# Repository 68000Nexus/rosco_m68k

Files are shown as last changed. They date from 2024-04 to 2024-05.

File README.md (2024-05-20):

# Really Old-School Computer - M68K
## A Motorola 68k Single-Board Computer

> **Note**: This is the **develop** branch, where the latest development files live. It is not guaranteed to contain stable code or working designs at any given point. If you are looking for code to use with your board or stable designs, these can be found on the relevant release branches: The [latest 2.4 release branch](https://github.com/rosco-m68k/rosco_m68k/tree/release/version-2.4) for revision 2.x boards, the [1.3 release branch](https://github.com/rosco-m68k/rosco_m68k/tree/release/version-1.3), the [1.2 release branch](https://github.com/rosco-m68k/rosco_m68k/tree/release/revision-1.2) for **revision 1.2** boards, or the [1.1 release branch](https://github.com/rosco-m68k/rosco_m68k/tree/release/revision-1.1) (or the [1.01 release branch if you have firmware 1.01](https://github.com/rosco-m68k/rosco_m68k/tree/release/revision-1.01)) for **revision 1 boards**. Code built or PCBs manufactured from the develop branch are likely to contain development and pre-production bugs, be incomplete, or just plain not work. Code and designs here are liable to change in utterly-incompatible ways without notice!

## Boards & Kits Available

> **The best way to support this project is to buy PCBs and kits - visit the <a href='https://store.rosco-m68k.com'>Official Store</a>!**

> Alternatively, you can <a href="https://ko-fi.com/rosco_m68k">buy us a coffee</a> if you like, it would be much appreciated! 😊

## What is this?

This repository holds design files, firmware and software for the Really Old-School Computer 
(M68k) single-board computer, AKA the rosco_m68k. This is a fully-featured, programmable,
extensible and capable 16/32-bit retro computer that is completely open source.

This project contains all the design files and source code for the project. For 
documentation (including assembly instructions) please see https://rosco-m68k.com

You can find the project along with some logs about its development history
on Hackaday: https://hackaday.io/project/164305-yet-another-m68k-homebrew

* All Software released under the MIT licence. See LICENSE for details.
* All Hardware released under the CERN Open Hardware licence.See LICENCE.hardware.txt.
* All Documentation released under Creative Commons Attribution. See https://creativecommons.org/licenses/by/2.0/uk/
* OSHWA-certified Open Source Hardware

## Specifications

Current main board

### Hardware

The hardware specifications for the rosco_m68k are:

* MC68010P10 at 10MHz.
* XR68C681P provides UART, Timers and SD Card / SPI
* 1MB RAM (0x0 - 0xFFFFF)
* 1MB ROM (0xE00000 - 0xEFFFFF)
* 1MB IO space (0xF00000 - 0xFFFFFF)
* High-speed decode and glue logic handled by Atmel F22V10C PLDs.
* Comprehensive expansion and IO connectors allow the system to be easily expanded!

### Software

* A serial bootloader that can load software via the UART (with Kermit protocol)
* Lots of example code and community projects
* Rich firmware interface for with serial and video console for easy programming
* Programmable in assembly, C and (a limited subset of) C++.
* Easy68K-compatible* TRAP 15 (IO) handler
* A growing collection of system libraries and utility code
* Custom Homebrew tap with toolchain - assembly built with VASM; C/C++ built with GCC 10.2.

(*) The firmware is _mostly_ Easy68K compatible - certain functions are not implemented due to the serial nature of IO.

## Getting boards fabricated

If you want to get boards fabricated, we recommend JLCPCB - they do all of our commercial boards. 
These are the options you'll want when ordering from them (these should be readily adaptable to other fabs too!)

JLCPCB Fab Options

## Certification

The rosco_m68k is an OSHWA-certified Open Source Hardware project!

<p align='center'>
OSHWA Certified OSHWA Certification UK000006
</p>
<p align='center'>
https://certification.oshwa.org/uk000006.html
</p>

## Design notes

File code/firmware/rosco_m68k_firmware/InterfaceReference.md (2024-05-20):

# rosco_m68k Firmware - Memory & Interfaces
## Firmware version 2.0

This document describes the interfaces provided for programmers,
hardware integrators and those expanding the rosco_m68k, as it
applies to firmware revision 2.0. 

The information contained herein is accurate and complete as far
as possible, and will be kept updated as firmware 2.0 is developed.

# Contents

* 1. TRAP Interfaces for User Code
  * 1.1. SPI & Block device IO (TRAP 13)
    * 1.1.1 Example Usage
    * 1.1.2 Functions
      * 1.1.2.1 CHECK_SD_SUPPORT (Function #0)
      * 1.1.2.2 SD_INIT (Function #1)
      * 1.1.2.3 SD_READ_BLOCK (Function #2)
      * 1.1.2.4 SD_WRITE_BLOCK (Function #3)
      * 1.1.2.5 SD_READ_REGISTER (Function #4)
      * 1.1.2.6 CHECK_SPI (Function #5)
      * 1.1.2.7 SPI_INIT (Function #6)
      * 1.1.2.8 SPI_ASSERT_CS (Function #7)
      * 1.1.2.9 SPI_DEASSERT_CS (Function #8)
      * 1.1.2.10 SPI_TRANSFER_BYTE (Function #9)
      * 1.1.2.11 SPI_TRANSFER_BUFFER (Function #10)
      * 1.1.2.12 SPI_RECV_BYTE (Function #11)
      * 1.1.2.13 SPI_RECV_BUFFER (Function #12)
      * 1.1.2.14 SPI_SEND_BYTE (Function #13)
      * 1.1.2.15 SPI_SEND_BUFFER (Function #14)
      * 1.1.2.16 CHECK_ATA_SUPPORT (Function #15)
      * 1.1.2.17 ATA_INIT (Function #16)
      * 1.1.2.18 ATA_READ_SECTORS (Function #17)
      * 1.1.2.19 ATA_WRITE_SECTORS (Function #18)
      * 1.1.2.20 ATA_IDENTIFY (Function #19)
  * 1.2. Character device IO routines (TRAP 14)
    * 1.2.1 Example Usage
    * 1.2.2 Functions
      * 1.2.2.1 PRINT (Function #0)
      * 1.2.2.2 PRINTLN (Function #1)
      * 1.2.2.3 SENDCHAR (Function #2)
      * 1.2.2.4 RECVCHAR (Function #3)
      * 1.2.2.5 PRINTCHAR (Function #4)
      * 1.2.2.6 SETCURSOR (Function #5)
      * 1.2.2.7 CHECKCHAR (Function #6)
      * 1.2.2.8 CHECK_DEVICE_SUPPORT (Function #7)
      * 1.2.2.9 GET_DEVICE_COUNT (Function #8)
      * 1.2.2.10 GET_DEVICE (Function #9)
      * 1.2.2.11 ADD_DEVICE (Function #10)
      * 1.2.2.12 DEVICE_RECVCHAR (Function #11)
      * 1.2.2.13 DEVICE_SENDCHAR (Function #12)
      * 1.2.2.14 DEVICE_CHECKCHAR (Function #13)
      * 1.2.2.15 RESERVED (Function #14)
      * 1.2.2.16 RESERVED (Function #15)
      * 1.2.2.17 DEVICE_CTRL (Function #16)
      * 1.2.2.18 INPUTCHAR (Function #17)
      * 1.2.2.19 CHECKINPUT (Function #18)
  * 1.3. Easy68k compatibility layer (TRAP 15)
    * 1.3.1 Example Usage
    * 1.3.2 Functions
      * 1.3.2.1 PRINTLN_LEN (Function #0)
      * 1.3.2.2 PRINT_LEN (Function #1)
      * 1.3.2.3 READSTR (Function #2)
      * 1.3.2.4 DISPLAYNUM_SIGNED (Function #3)
      * 1.3.2.5 READNUM (Function #4)
      * 1.3.2.6 READCHAR (Function #5)
      * 1.3.2.7 SENDCHAR (Function #6)
      * 1.3.2.8 CHECKINPUT (Function #7)
      * 1.3.2.9 GETUPTICKS (Function #8)
      * 1.3.2.10 TERMINATE (Function #9)
      * 1.3.2.11 MOVEXY (Function #11)
      * 1.3.2.12 SETECHO (Function #12)
      * 1.3.2.13 PRINTLN_SZ (Function #13)
      * 1.3.2.14 PRINT_SZ (Function #14)
      * 1.3.2.15 PRINT_UNSIGNED (Function #15)
      * 1.3.2.16 SETDISPLAY (Function #16)
      * 1.3.2.17 PRINTSZ_NUM (Function #17)
      * 1.3.2.18 PRINTSZ_READ_NUM (Function #18)
      * 1.3.2.19 PRINTNUM_SIGNED_WIDTH (Function #20)
* 2. System Data Area memory map
  * 2.1. Exception vectors
  * 2.2. Basic System Data Block (SDB)
  * 2.3. Extension Function Pointer Table (EFPT)
  * 2.4. Video IO Data Area (VDA)
  * 2.5. Firmware Reserved Area 1 (Internal)
  * 2.6. Firmware Reserved Area 2 (BSS)
* 3. Character Devices
  * 3.1 General Information
  * 3.2. The `CHAR_DEVICE` structure
  * 3.3. Device function calling conventions

# 1. TRAP Interfaces for User Code

The firmware provides a set of basic IO routines intended for use
from user code. Because some of these routines may require the CPU
to be in Supervisor mode, they are accessed via the M68k TRAP
instruction. Execution of this instruction causes the CPU to jump
to an exception vector (initialized by the firmware) as if an
exception were being processed. Context is stored on the stack
and Supervisor mode is entered automatically.

Currently, three TRAPs are used by the firmware:

* TRAP 13 provides rosco_m68k's native block device IO routines (SD)
* TRAP 14 provides rosco_m68k's native serial device IO routines (UART/Console)
* TRAP 15 provides basic IO routines that are broadly Easy68k-compatible(*)

All other TRAP vectors are unused at boot-time (and initialized to no-op
handlers). Extension code, drivers and user code are free to re-use
these vectors as they see fit.

The standard TRAP handlers use various registers as arguments, and
may also use one or more registers to return values to the 
calling code. These registers are documented in the following 
sections. In all cases, all registers other than those stated
in this documentation are preserved.

**Note** that the standard firmware TRAP handlers rely on the 
integrity of the System Data Area in memory. If this area is
reused or corrupted, these routines may not function properly.

(*) Note that the Easy68k layer may optionally be omitted from the 
firmware build. In such cases, the functions offered on TRAP 15 will
not be available, and that TRAP vector may be reused.

## 1.1. Block device IO (TRAP 13)

TRAP 13 provides access to the block-device IO functionality
provided by the firmware. At present, this means SD cards.

Register D0.L is expected to contain the function code (note that
this is different to the TRAP 14 handler!). Other arguments
depend on the specific function, and are documented below.

In all cases, registers used as aguments (including D0.L) are **not** 
guaranteed to be preserved. All other registers are preserved.

Function codes outside the range documented here are considered
reserved for future expansion, and should not be used by integrators
or other code. The exception to this is where the user program 
is intended to take complete control of the system, in which case
the TRAP handlers, and the SDA that underpins them, may be entirely
replaced in the scope of that program.

### 1.1.1 Example Usage

An example of using function 2 (SD_READ_BLOCK) of TRAP 13 is:

```
SD_read_block::
    movem.l A0-A2/D1,-(A7)
    move.l  (20,A7),A1
    move.l  (24,A7),D1
    move.l  (28,A7),A2
    move.l  #2,D0
    trap    #13
    movem.l (A7)+,A0-A2/D1
    rts
```

With GCC as the compiler, this could be called directly from C, 
with the prototype: 

```
bool SD_read_block(SDCard *sd, uint32_t block, void *buf);
```
 
### 1.1.2 Functions

#### 1.1.2.1 CHECK_SD_SUPPORT (Function #0)

**Arguments**

* D0.L - 0 (Function code)

**Modifies**

* `D0.L` - Return value

**Description**

Determine whether SD Card support is present in the Firmware.

Where SD Card support is available, this will return the magic
number $1234FEDC in D0.L. 

Any other value indicates that support is not available. In this
case, none of the SD Card routines should be used.

With Firmware 2.0, SD support is always available. However, this
routine is retained to allow easy backward-compatibility.

#### 1.1.2.2 SD_INIT (Function #1)

**Arguments**

* `D0.L` - 1 (Function code)
* `A1`   - Pointer to an SDCard struct

**Modifies**

* `D0.L` - Return value
* `A0`   - Modified arbitrarily
* `A1`   - May be modified arbitrarily

**Description**

Attempt to initialize the SD Card. 

The memory pointed to by A1 will be a SDCard structure - see
sdfat.h in the standard libraries for details.

The return value in D0.L will be one of the SDInitStatus
codes - `SD_INIT_OK` (ordinal 0) indicates success, while failure 
is indicated by any other value. Again, see sdfat.h for details.

#### 1.1.2.3 SD_READ_BLOCK (Function #2)

**Arguments**

* `D0.L` - 2 (Function code)
* `D1.L` - Block number to read
* `A1`   - Pointer to an initialized SDCard struct
* `A2`   - Pointer to a 512-byte buffer

**Modifies**

* `D0.L` - Return value
* `D1.L` - May be modified arbitrarily
* `A0`   - Modified arbitrarily
* `A1`   - May be modified arbitrarily
* `A2`   - May be modified arbitrarily

**Description**

Read a 512-byte block from the SD Card into the buffer
pointed to by A2.

Returns 0 in D0.L to indicate failure, any other value
indicates success.

#### 1.1.2.4 SD_WRITE_BLOCK (Function #3)

**Arguments**

* `D0.L` - 3 (Function code)
* `D1.L` - Block number to write
* `A1`   - Pointer to an initialized SDCard struct
* `A2`   - Pointer to a 512-byte buffer

**Modifies**

* `D0.L` - Return value
* `D1.L` - May be modified arbitrarily
* `A0`   - Modified arbitrarily
* `A1`   - May be modified arbitrarily
* `A2`   - May be modified arbitrarily

**Description**

Write a 512-byte block from the buffer pointed to by A2 to
the SD Card..

Returns 0 in D0.L to indicate failure, any other value
indicates success.

#### 1.1.2.5 SD_READ_REGISTER (Function #4)

**Arguments**

* `D0.L` - 4 (Function code)
* `D1.L` - Register number to read (translates directly to a CMD)
* `A1`   - Pointer to an initialized SDCard struct
* `A2`   - Pointer to a 16-byte buffer

**Modifies**

* `D0.L` - Return value
* `D1.L` - May be modified arbitrarily
* `A0`   - Modified arbitrarily
* `A1`   - May be modified arbitrarily
* `A2`   - May be modified arbitrarily

**Description**

Read an SD Card register block from the SD Card into the buffer
pointed to by A2.

Returns 0 in D0.L to indicate failure, any other value
indicates success.

#### 1.1.2.6 CHECK_SPI (Function #5)

**Arguments**

* `D0.L` - 5 (Function code)

**Modifies**

* `D0.L` - Return value

**Description**

Determine whether SPI support is present in the Firmware.

Where SPI Card support is available, this will return the magic
number $1234FEDC in D0.L. 

Any other value indicates that support is not available. In this
case, none of the SPI routines should be used.

With Firmware 2.0, SD support is always available. However, this
routine is retained to allow easy backward-compatibility.

#### 1.1.2.7 SPI_INIT (Function #6)

**Arguments**

* `D0.L` - 6 (Function code)

**Modifies**

* `D0.L` - Result (0 = OK, otherwise failed)
* `A0`   - Modified arbitrarily

**Description**

Initialize the SPI interface. This sets the SPI pins to the 
appropriate modes (input vs output).

#### 1.1.2.8 SPI_ASSERT_CS (Function #7)

**Arguments**

* `D0.L` - 7 (Function code)
* `D1.L` - Device number (0 or 1)

**Modifies**

* `D0.L` - Result (0 = failed, otherwise OK)
* `A0`   - Modified arbitrarily

**Description**

Assert the appropriate CS line. Note that asserting one line 
*does not* automatically deassert the other!

#### 1.1.2.9 SPI_DEASSERT_CS (Function #8)

**Arguments**

* `D0.L` - 8 (Function code)
* `D1.L` - Device number (0 or 1)

**Modifies**

* `D0.L` - Result (0 = failed, otherwise OK)
* `A0`   - Modified arbitrarily

**Description**

Deassert the appropriate CS line. 

#### 1.1.2.10 SPI_TRANSFER_BYTE (Function #9)

**Arguments**

* `D0.L` - 9 (Function code)
* `D1.L` - Byte to send

**Modifies**

* `D0.L` - Byte received
* `A0`   - Modified arbitrarily

**Description**

Send and receive a byte (exchange) via SPI.

#### 1.1.2.11 SPI_TRANSFER_BUFFER (Function #10)

**Arguments**

* `D0.L` - 10 (Function code)
* `A1.L` - Pointer to buffer
* `D1.L` - Number of bytes

**Modifies**

* `D0.L` - Count exchanged
* `A0`   - Modified arbitrarily
* `A1`   - Possibly modified

**Description**

Transfer count (`D1.L`) bytes from the given buffer, exchanging them 
with bytes received at the same time (and returned in the buffer).

Note that the buffer pointer may be modified, so keep a copy locally.

#### 1.1.2.12 SPI_RECV_BYTE (Function #11)

**Arguments**

* `D0.L` - 11 (Function code)

**Modifies**

* `D0.L` - Byte received
* `A0`   - Modified arbitrarily

**Description**

Send and receive a byte (exchange) via SPI.

#### 1.1.2.13 SPI_RECV_BUFFER (Function #12)

**Arguments**

* `D0.L` - 12 (Function code)
* `A1.L` - Pointer to buffer
* `D1.L` - Number of bytes

**Modifies**

* `D0.L` - Count received
* `A0`   - Modified arbitrarily
* `A1`   - Possibly modified

**Description**

Receive count (`D1.L`) bytes into the given buffer.
Note that the buffer pointer may be modified, so keep a copy locally.

#### 1.1.2.14 SPI_SEND_BYTE (Function #13)

**Arguments**

* `D0.L` - 13 (Function code)
* `D1.L` - Byte to send

**Modifies**

* `A0`   - Modified arbitrarily
* `D1.L` - Possibly trashed

**Description**

Send and receive a byte (exchange) via SPI.

#### 1.1.2.15 SPI_SEND_BUFFER (Function #14)

**Arguments**

* `D0.L` - 14 (Function code)
* `A1.L` - Pointer to buffer
* `D1.L` - Number of bytes

**Modifies**

* `D0.L` - Count received
* `A0`   - Modified arbitrarily
* `A1`   - Possibly modified

**Description**

Send count (`D1.L`) bytes from the given buffer.
Note that the buffer pointer may be modified, so keep a copy locally.

#### 1.1.2.16 CHECK_ATA_SUPPORT (Function #15)

**Arguments**

* `D0.L` - 15 (Function code)

**Modifies**

* `D0.L` - Return value

**Description**

Determine whether ATA support is present in the Firmware.

Where ATA support is available, this will return the magic
number $1234FEDC in D0.L. 

Any other value indicates that support is not available. In this
case, none of the ATA routines should be used.

With Firmware 2.0, ATA support is always available. However, this
routine is retained to allow easy backward-compatibility.

#### 1.1.2.17 ATA_INIT (Function #16)

**Arguments**

* `D0.L` - 16 (Function code)
* `D1.L` - 0 (ATA Master) or 1 (ATA slave)
* `A1`   - Pointer to an ATADevice struct

**Modifies**

* `D0.L` - Return value
* `D1.L` - May be modified arbitrarily
* `A0`   - Modified arbitrarily
* `A1`   - May be modified arbitrarily

**Description**

Attempt to initialize an ATA device. 

The memory pointed to by A1 will be a ATADevice structure - see
ata.h in the standard libraries for details.

The return value in D0.L will be one of the ATAInitStatus
codes - `ATA_INIT_OK` (ordinal 0) indicates success, while failure 
is indicated by any other value. Again, see ata.h for details.

#### 1.1.2.18 ATA_READ_SECTORS (Function #17)

**Arguments**

* `D0.L` - 17 (Function code)
* `D1.L` - LBA sector number to read
* `D2.L` - Number of sectors to read
* `A1`   - Pointer to an initialized ATADevice struct
* `A2`   - Pointer to a (512 * D2.L)-byte buffer

**Modifies**

* `D0.L` - Return value
* `D1.L` - May be modified arbitrarily
* `A0`   - Modified arbitrarily
* `A1`   - May be modified arbitrarily
* `A2`   - May be modified arbitrarily

**Description**

Read the number of 512-byte sectors (indicated by `D2.L`) from the 
ATA device into the buffer pointed to by `A2`.

Returns the actual number of sectors read in `D0.L`.

#### 1.1.2.19 ATA_WRITE_SECTORS (Function #18)

**Arguments**

* `D0.L` - 18 (Function code)
* `D1.L` - LBA sector number to write
* `D2.L` - Number of sectors to write
* `A1`   - Pointer to an initialized ATADevice struct
* `A2`   - Pointer to a (512 * D2.L)-byte buffer

**Modifies**

* `D0.L` - Return value
* `D1.L` - May be modified arbitrarily
* `A0`   - Modified arbitrarily
* `A1`   - May be modified arbitrarily
* `A2`   - May be modified arbitrarily

**Description**

Write the number of 512-byte sectors (indicated by `D2.L`) from the 
buffer pointed to by `A2` to the ATA device, starting at the LBA sector
indicated by `D1.L`.

Returns the actual number of sectors written in `D0.L`.

#### 1.1.2.20 ATA_IDENTIFY (Function #19)

**Arguments**

* `D0.L` - 19 (Function code)
* `A1`   - Pointer to an initialized ATADevice struct
* `A2`   - Pointer to a 512-byte buffer

**Modifies**

* `D0.L` - Return value (0 = failed, 1 = success)
* `D1.L` - May be modified arbitrarily
* `A0`   - Modified arbitrarily
* `A1`   - May be modified arbitrarily
* `A2`   - May be modified arbitrarily

**Description**

Issue an ATA `IDENTIFY` command to the specified `ATADevice`, and return
the results in the supplied buffer.

Returns 1 in `D0.L` if successful, 0 otherwise.

## 1.2. Basic IO routines (TRAP 14)

TRAP 14 provides access to the character-based IO functionality 
provided by the firmware. This includes the default UART and
console.

Register D1.L is expected to contain the function code. Other arguments
depend on the specific function, and are documented below.

In all cases, registers used as aguments (**excluding** D1.L, which 
will be preserved unless explicitly documented as used for a return
value) are **not** guaranteed to be preserved. All 
other registers are preserved.

Function codes outside the range documented here are considered
reserved for future expansion, and should not be used by integrators
or other code. The exception to this is where the user program 
is intended to take complete control of the system, in which case
the TRAP handlers, and the SDA that underpins them, may be entirely
replaced in the scope of that program.

### 1.2.1 Example Usage

An example of calling function 1 (PRINTLN) of TRAP 14 is:

```
DO_PRINTLN:
    move.l  #1,D1
    lea.l   MYSTRING,A0
    trap    #14

; ... later

MYSTRING    dc.b    "Hello, World!", 0
```

### 1.2.2 Functions

#### 1.2.2.1 PRINT (Function #0)

**Arguments**

* `D1.L` - 0 (Function code)
* `A0`   - Pointer to null-terminated string to print

**Modifies**

* `A0`   - Will point to the memory location following the null terminator

**Description**

Print the null-terminated string pointed to by `A0` to the system's
*default console*. 

Where the default console is a serial terminal, this routine may block until
there is space in the UART's transmit buffer for the character - as such, 
it is not suitable for use in time- or latency-critical code (e.g. interrupt 
handlers).

The default console is initialized at boot-time by the firmware, and 
may be the V9958 console (where available), or the *default serial UART*.
For details on the default UART, see the `SENDCHAR` function.

System integrators and third-party hardware developers may also override
the default console (for example to output to third-party video 
hardware). See section 2.3 for details.

#### 1.2.2.2 PRINTLN (Function #1)

**Arguments**

* `D1.L` - 1 (Function code)
* `A0`   - Pointer to null-terminated string to print

**Modifies**

* `A0`   - Will point to the memory location following the null terminator

**Description**

Print the null-terminated string pointed to by `A0` to the system's
*default console* followed by a CR/LF sequence.

Where the default console is a serial terminal, this routine may block until
there is space in the UART's transmit buffer for the character - as such, 
it is not suitable for use in time- or latency-critical code (e.g. interrupt 
handlers).

The default console is initialized at boot-time by the firmware, and 
may be the V9958 console (where available), or the *default serial UART*.
For details on the default UART, see the `SENDCHAR` function.

System integrators and third-party hardware developers may also override
the default console (for example to output to third-party video 
hardware). See section 2.3 for details.

#### 1.2.2.3 SENDCHAR (Function #2)

**Arguments**

* `D1.L` - 2 (Function code)
* `D0.B` - Character to send

**Modifies**

Nothing

**Description**

Synchronously send the character contained in `D0.B` via the system's
*default UART*. This routine may block until there is space in the 
UART's transmit buffer for the character - as such, it is not suitable
for use in time- or latency-critical code (e.g. interrupt handlers).

The default UART is initialized at boot-time by the firmware, and
will generally be the "best" serial UART available (with the 
fallback being the MC68901 UART that is expected to be always installed).

System integrators and third-party hardware developers may also override
the default UART (for example to utilise third-party hardware). 
See section 2.3 for details.

#### 1.2.2.4 RECVCHAR (Function #3)

**Arguments**

* `D1.L` - 3 (Function code)

**Modifies**

* `D0.B` - Returns the received character

**Description**

Synchronously receive a character via the system's *default UART*,
and return it in `D0.B`. If no character is immediately available, this
routine will block until one becomes available. As such, it is not suitable
for use in time- or latency-critical code (e.g. interrupt handlers).

The default UART is initialized at boot-time by the firmware, and
will generally be the "best" serial UART available (with the 
fallback being the MC68901 UART that is expected to be always installed).

System integrators and third-party hardware developers may also override
the default UART (for example to utilise third-party hardware). 
See section 2.3 for details.

#### 1.2.2.5 PRINTCHAR (Function #4)

**Arguments**

* `D1.L` - 4 (Function code)
* `D0.B` - Character to print

**Modifies**

Nothing

**Description**

Print the character in `D0.B` to by `A0` to the system's *default console*.

Where the default console is a serial terminal, this routine may block until
there is space in the UART's transmit buffer for the character - as such, 
it is not suitable for use in time- or latency-critical code (e.g. interrupt 
handlers).

The default console is initialized at boot-time by the firmware, and 
may be the V9958 console (where available), or the *default serial UART*.
For details on the default UART, see the `SENDCHAR` function.

System integrators and third-party hardware developers may also override
the default console (for example to output to third-party video 
hardware). See section 2.3 for details.

#### 1.2.2.6 SETCURSOR (Function #5)

**Arguments**

* `D1.L` - 5 (Function code)
* `D0.B` - 0 to hide cursor, non-zero to show

**Modifies**

Nothing

**Description**

Show or hide the cursor on the *default console*. Where this is not possible]
(e.g. where the default console is a serial terminal) this routine does
nothing.

The default console is initialized at boot-time by the firmware, and 
may be the V9958 console (where available), or the *default serial UART*.
For details on the default UART, see the `SENDCHAR` function.

System integrators and third-party hardware developers may also override
the default console (for example to output to third-party video 
hardware). See section 2.3 for details.

#### 1.2.2.7 CHECKCHAR (Function #6)

**Arguments**

* `D1.L` - 6 (Function code)

**Modifies**

* `D0.B` - 0 if no character waiting, nonzero otherwise

**Description**

Determine whether the system's *default UART* has a character waiting to
be received, returning non-zero in `D0.B` if so, zero otherwise. 

This can be used to determine whether a call to `RECVCHAR` will block.
Note that this function may clear error flags and other status information.

The default UART is initialized at boot-time by the firmware, and
will generally be the "best" serial UART available (with the 
fallback being the MC68901 UART that is expected to be always installed).

System integrators and third-party hardware developers may also override
the default UART (for example to utilise third-party hardware). 
See section 2.3 for details.

#### 1.2.2.8 CHECK_DEVICE_SUPPORT (Function #7)

**Arguments**

* `D1.L` - 7 (Function code)

**Modifies**

* `D0.L` - Return value

**Description**

Check if the new _Character Device Support_ (available since firmware
2.30) is available.

Where support is available, this will return the magic number $1234FEDC 
in `D0.L`.

Any other value indicates that support is not available. In this
case, none of the character device routines should be used.

#### 1.2.2.9 GET_DEVICE_COUNT (Function #8)

**Arguments**

* `D1.L` - 8 (Function code)

**Modifies**

* `D0.W` - Return value

**Description**

Returns the number of character devices the firmware knows about in 
`D0.W`.

#### 1.2.2.10 GET_DEVICE (Function #9)

**Arguments**

* `D1.L` - 9 (Function code)
* `D0.W` - 0-based index of the desired device
* `A0`   - Points to a `CHAR_DEVICE` structure (32 bytes)

**Modifies**

* `D0.B` - `0` if the device number is not valid, nonzero otherwise
* `A0`   - Trashed

**Description**

Populates the supplied device structure with data for the
specified device number. 

Note that the data is copied into the structure you supply,
you cannot use this to modify system data structures.

#### 1.2.2.11 ADD_DEVICE (Function #10)

**Arguments**

* `A0`   - Pointer to a new `CHAR_DEVICE` structure
* `D1.L` - 10 (Function code)

**Modifies**

* `D0.B` - 0-15 index of the device. Any other value indicates failure.

**Description**

Adds a new character device at the next available slot. There
are sixteen slots - if they are all full, this function will return
a value >15 to indicate failure.

#### 1.2.2.12 DEVICE_RECVCHAR (Function #11)

**Arguments**

* `D1.L` - 11 (Function code)
* `A0`   - Pointer to the `CHAR_DEVICE` structure (obtained via `GET_DEVICE`)

**Modifies**

* `D0.B` - Returns the received character
* `A0`   - Trashed 

**Description**

Synchronously receive a character via the character device in the supplied
`CHAR_DEVICE` structure, and return it in `D0.B`. 

If no character is immediately available, this routine _may_ block until one
becomes available. As such, it is not suitable for use in time- or 
latency-critical code (e.g. interrupt handlers).

#### 1.2.2.13 DEVICE_SENDCHAR (Function #12)

**Arguments**

* `D1.L` - 12 (Function code)
* `D0.B` - Character to send
* `A0`   - Pointer to the `CHAR_DEVICE` structure (obtained via `GET_DEVICE`)

**Modifies**

* `A0`   - Trashed 

**Description**

Synchronously send the character contained in `D0.B` via the character 
device referenced by the supplied `CHAR_DEVICE` structure. 

This routine _may_ block until there is space in the device's buffer
for the character - as such, it is not suitable for use in time- or 
latency-critical code (e.g. interrupt handlers).

#### 1.2.2.14 DEVICE_CHECKCHAR (Function #13)

**Arguments**

* `D1.L` - 13 (Function code)
* `A0`   - Pointer to the `CHAR_DEVICE` structure (obtained via `GET_DEVICE`)

**Modifies**

* `D0.B` - 0 if no character waiting, nonzero otherwise
* `A0`   - Trashed 

**Description**

Determine whether the the character device referenced by the supplied
 `CHAR_DEVICE` structure has a character waiting to be received, returning 
 non-zero in `D0.B` if so, zero otherwise. 

This can be used to determine whether a call to `DEVICE_RECVCHAR` will 
block if called for the same device.

Note that this function _may_ clear error flags and other status information.

#### 1.2.2.15 RESERVED (Function #14)

This function code is reserved for future use and should not be called.

#### 1.2.2.16 RESERVED (Function #15)

This function code is reserved for future use and should not be called.

#### 1.2.2.17 DEVICE_CTRL (Function #16)

**Arguments**

* `D1.L` - 16 (Function code)
* `D0.L` - Command (low-byte) and optional data
* `D2.L` - 32-bit command-specific parameter
* `A0`   - Pointer to the `CHAR_DEVICE` structure (obtained via `GET_DEVICE`)

**Modifies**

* `D0.L` - 0 if unknown command, device/command-specific result otherwise
* `A0`   - Trashed 

**Description**

Send a device-specific command, with optional parameters in the high
24 bits of `D0` and the full 32-bits of `D2`.

The commands supported, the parameters they take, and the return value
of this function are all device specific. See the specific documentation
for the device (which can be identified by the device type in the 
`CHAR_DEVICE` block) for details.

#### 1.2.2.18 INPUTCHAR (Function #17)

**Arguments**

* `D1.L` - 17 (Function code)

**Modifies**

* `D0.B` - The read character

**Description**

Read a character from the default input device. Will block until a
character is available.

In systems where the rosco_m68k (or compatible) keyboard is connected to the
second UART, this will check the keyboard. 

Otherwise, the default input will usually be the main UART.

#### 1.2.2.19 CHECKINPUT (Function #18)

**Arguments**

* `D1.L` - 18 (Function code)

**Modifies**

* `D0.B` - 0 if no character waiting, nonzero otherwise

**Description**

Check the default input device for a waiting character.

In systems where the rosco_m68k (or compatible) keyboard is connected to the
second UART, this will check the keyboard. 

Otherwise, the default input will usually be the main UART.

## 1.3. Easy68k compatibility layer (TRAP 15)

TRAP 15 provides an (optional, included by default) Easy68k-compatible
IO interface. The aim is to allow many common Easy68k programs to be 
run on the rosco_m68k without modification.

Currently only a subset of the Easy68K tasks are implemented. Output 
will always go to the **default console** (See section 1.1.2.1) and input
will be via the **default UART** (See section 1.1.2.3). Depending on
capabilities of the input and output devices, some functions may not
be available in all contexts (for example, cursor movement and color
setting will not be available where output is via UART).

These functions are called by loading the task number into `D0` and setting
up other registers as documented below, and then calling `TRAP #15`.

### 1.3.1 Example Usage

An example of calling function 0 (PRINTLN with length) of TRAP 15 is:

```
DO_EASY68K_PRINTLN_LEN:
    move.l  #0,D0
    move.w  #13,D1
    lea.l   MYSTRING,A1
    trap    #15

; ... later

MYSTRING    dc.b    "Hello, World!"
```

### 1.3.2 Functions

#### 1.3.2.1 PRINTLN_LEN (Function #0)

**Arguments**

* `D0.L` - 0 (Function code)
* `D1.W` - String length (max 255)
* `A1` - Points to the string

**Modifies**

* `D1` - Trashed
* `A1` - Points to memory location after the last printed character

**Description**

Print the string at (A1), D1.W bytes long (max 255) with carriage return
and line feed (CR, LF) to the system's *default console*. 

See also: Function 13

#### 1.3.2.2 PRINT_LEN (Function #1)

**Arguments**

* `D0.L` - 1 (Function code)
* `D1.W` - String length (max 255)
* `A1` - Points to the string

**Modifies**

* `D1` - Trashed
* `A1` - Points to memory location after the last printed character

**Description**

Print the string at (A1), D1.W bytes long (max 255) **without** carriage return
and line feed (CR, LF) to the system's *default console*. 

See also: Function 14

#### 1.3.2.3 READSTR (Function #2)

**Arguments**

* `D0.L` - 2 (Function code)
* `A0` - Pointer to buffer in which to store string

**Modifies**

* `D1.W` - Returns length of read string (Max 80)
* `(A1)` - Returns the string

**Description**

Read string from keyboard and store at (A1), NULL terminated, length retuned in D1.W (max 80). 

#### 1.3.2.4 DISPLAYNUM_SIGNED (Function #3)

**Arguments**

* `D0.L` - 3 (Function code)
* `D1.L` - Number to display

**Modifies**

* `D1` - Possibly trashed

**Description**

Print signed number in D1.L in decimal (in smallest field) to the system's
*default console*.

See also: Functions 15 & 20

#### 1.3.2.5 READNUM (Function #4)

**Arguments**

* `D0.L` - 4 (Function code)

**Modifies**

* `D1.L` - Returns the read number

**Description**

Read a number from the keyboard into D1.L.

See also: Functions 15 & 20

#### 1.3.2.6 READCHAR (Function #5)

**Arguments**

* `D0.L` - 5 (Function code)

**Modifies**

* `D1.B` - The read character.

**Description**

Read single character from the keyboard into D1.B.

**Note** Unlike Easy68k, this will block until input is available.

#### 1.3.2.7 SENDCHAR (Function #6)

**Arguments**

* `D0.L` - 6 (Function code)
* `D1.B` - Character to display

**Modifies**

* `D1` - Trashed

**Description**

Display single character in D1.B.

#### 1.3.2.8 CHECKINPUT (Function #7)

**Arguments**

* `D0.L` - 7 (Function code)

**Modifies**

* `D1.B` - 1 if input pending, 0 otherwise

**Description**

Set D1.B to 1 if keyboard input is pending, otherwise set to 0. 
Use Function 5 to read pending key.

**Notes**

**This function is to be avoided if possible**.

Using this function doesn't make a lot of sense in the current rosco_m68k 
environment, because all input is via the UART. This means that, while this 
function _is_ implemented, its meaning is subtly different from the Easy68K
equivalent - here true result means there is serial data waiting, not 
specifically a user keypress.

That's not the worst of it, however - if the MC68901 UART is currently the
system's *default UART*, **using this task may actually be harmful**.
It may silently clear any errors the UART is signalling. This is 
because it works by reading the Buffer Full indicator bit in the receiver
status register, which has the effect of _also_ clearing the error flags
(e.g. overrun) in that same register. Normally, these would be checked 
during a receive, but this task doesn't check them _at all_ and so could 
lead to errors being ignored / discarded.

So, if you must use this task, keep all this in mind! 

See also: Function 5                       

#### 1.3.2.9 GETUPTICKS (Function #8)

**Arguments**

* `D0.L` - 8 (Function code)

**Modifies**

* `D1.L` - Current number of upticks

**Description**

Return upticks (time in hundredths of a second since boot) in D1.L.

**Notes**

Easy68K defines this function as returning the count of "hundredths of a
second since midnight", but since the rosco_m68k doesn't have a real-time 
clock this just returns the system tick counter from the system data 
block (SDB), which is updated by the system tick handler (driven by a 
programmable interrupt which may be disabled).

Unfortunately this counter is only word-sized, and will roll over every
655.36 seconds (or 10.92 minutes if you prefer). It also isn't updated at
exactly 100HZ, so all-in-all this isn't really going to return "hundredths 
of a second since boot" unless you aren't particularly strict with your 
definition of "hundredths" and the computer was started less than ~11 minutes ago.

If you do need any kind of precision timing, you'll have to design some sort
of expansion that connects to the expansion bus :) 

#### 1.3.2.10 TERMINATE (Function #9)

**Arguments**

* `D0.L` - 9 (Function code)

**Modifies**

Nothing

**Description**

Terminate the program (Disables interrupts and halts the CPU).

This will never return - the only way back is through wetware
intervention.

#### 1.3.2.11 MOVEXY (Function #11)

**Arguments**

* `D0.L` - 11 (Function code)
* `D1.W` - Encoded position (see description)

**Modifies**

* `D1` - Trashed
* `D2` - Trashed
* `A0` - Trashed

**Description**

Position the cursor at ROW, COL. 

Support is not mandatory for any given console. E.g. requires ANSI support
on the receiving terminal where the default console is a UART.

* The high byte of D1.W holds the COL number (0-79),
* The low byte holds the ROW number (0-31).

0,0 is top left 79,31 is the bottom right (depending on terminal size).
Out of range coordinates are usually ignored (depends on terminal).

**Clear Screen : Set D1.W to $FF00**.

#### 1.3.2.12 SETECHO (Function #12)

**Arguments**

* `D0.L` - 12 (Function code)
* `D1.B` - 0 to disable, 1 to enable

**Modifies**

* `D1` - Trashed

**Description**

Keyboard Echo.

* D1.B = 0 to turn off keyboard echo.
* D1.B = non zero to enable it (default).

Echo is restored on 'Reset'.

#### 1.3.2.13 PRINTLN_SZ (Function #13)

**Arguments**

* `D0.L` - 13 (Function code)
* `A1` - Points to the string

**Modifies**

* `D1` - Trashed
* `A1` - Points to memory location after the last printed character

**Description**

Print the NULL-terminated string at (A1) with carriage return
and line feed (CR, LF) to the system's *default console*. 

See also: Function 0

#### 1.3.2.14 PRINT_SZ (Function #14)

**Arguments**

* `D0.L` - 14 (Function code)
* `A1` - Points to the string

**Modifies**

* `D1` - Trashed
* `A1` - Points to memory location after the last printed character

**Description**

Print the NULL-terminated string at (A1) **without** carriage return
and line feed (CR, LF) to the system's *default console*. 

See also: Function 1

#### 1.3.2.15 PRINT_UNSIGNED (Function #15)

**Arguments**

* `D0.L` - 15 (Function code)
* `D1.L` - Number to print
* `D2.B` - Base (2 through 36)

**Modifies**

* `D1` - Trashed
* `D2` - Trashed

**Description**

Display the unsigned number in D1.L converted to number base (2 
through 36) contained in D2.B.

For example, to display D1.L in base16 put 16 in D2.B

Values of D2.B outside the range 2 to 36 inclusive are ignored.

#### 1.3.2.16 SETDISPLAY (Function #16)

**Arguments**

* `D0.L` - 16 (Function code)
* `D1.B` - Option to set (see description)

**Modifies**

* `D1` - Trashed

**Description**

Adjust display properties

* D1.B = 0 to turn off the display of the input prompt.
* D1.B = 1 to turn on the display of the input prompt. (default)
* D1.B = 2 do not display a line feed when Enter pressed during Trap task #2 input
* D1.B = 3 display a line feed when Enter key pressed during Trap task #2 input (default)

Other values of D1 reserved for future use.

Input prompt display is enabled by default and by 'Reset'.

#### 1.3.2.17 PRINTSZ_NUM (Function #17)

**Arguments**

* `D0.L` - 17 (Function code)
* `D1.L` - Number to display
* `A1` - Pointer to string

**Modifies**

* `D1` - Trashed
* `A1` - Trashed

**Description**

Combination of functions 14 & 3.

* Display the NULL terminated string at (A1) without CR, LF then
* Display the number in D1.L, in base 10

#### 1.3.2.18 PRINTSZ_READ_NUM (Function #18)

**Arguments**

* `D0.L` - 18 (Function code)
* `A1` - Pointer to string

**Modifies**

* `D1.L` - Returns the resulting number
* `A1` - Trashed

**Description**

Combination of functions 14 & 4.

* Display the NULL terminated string at (A1) without CR, LF then
* Read a number from the keyboard into D1.L.

#### 1.3.2.19 PRINTNUM_SIGNED_WIDTH (Function #20)

**Arguments**

* `D0.L` - 20 (Function code)
* `D1.L` - Number to display
* `D2.B` - Field width

**Modifies**

* `D1` - Trashed
* `A1` - Trashed

**Description**

Display signed number in D1.L in decimal in field D2.B columns wide.

#2. System Data Area memory map

As standard, the first 4KB of RAM is reserved for system use. This section
details the layout of this memory area.

It is worth noting that if memory is in high demand and the program
being run intends to take full control of the system (i.e. not make
use of any of the firmware TRAP routines or default exception
handlers) then some of this are may be reused. As this is advanced
usage, it is assumed that you know what you need to keep in 
order for the basic machine to function.

All addresses listed in this section are physical addresses. If you
are programming for a system that has an MMU, you may need
to take virtual addressing into account and translate accordingly.

# 2. System Data Area memory map

## 2.1. Exception vectors

**Start Address**: 0x0
**End Address**: 0x3FF
**Size**: 0x400 (1024 bytes, 1KB)

This area contains the exception vectors for use by the CPU. 
See the MC68010 manual for the layout of this area.

In order to use custom exception handlers, you will want to
replace the appropriate vector with the address of your 
handler function. Writing exception handlers is beyond the
scope of this document.

It should be noted that this can be moved if a 68010 or higher
is in use. To achieve this, place the starting address of the
exception table in the VBR (Vector Base Register).

## 2.2. Basic System Data Block (SDB)

**Start Address**: 0x400
**End Address**: 0x41F
**Size**: 0x20 (32 bytes, 8 longwords)

This area contains the basic system data block, which is reserved
by the system for variable storage and data used by the standard
exception handlers and TRAP routines.

| Address | Size | Description |
|---|---|---|
| 0x400 | 4 | SDB Magic (0xB105D47A) |
| 0x404 | 4 | Status code (set by exception handlers) |
| 0x408 | 2 | Internal counter used by timer tick handler |
| 0x40A | 2 | System flags (see below) |
| 0x40C | 4 | Upticks counter, updated by timer tick handler |
| 0x410 | 1 | Easy68k 'echo on' flag |
| 0x411 | 1 | Easy68k 'prompt on' flag |
| 0x412 | 1 | Easy68k 'LF display' flag |
| 0x413 | 1 | Internal flags used by timer tick handler |
| 0x414 | 4 | Size of the first block of contiguious memory |
| 0x418 | 4 | Default UART base address |
| 0x41C | 4 | CPU Info (see below) |

For initialisation and usage, see `bootstrap.S` and the Easy68k `syscalls_asm.S`.

### System flags word (0x40A)

This word contains various flags that control system behaviour. The main use
at the moment is to prevent the system from using the on-board LEDs.

| Bit | Description |
|-----|---|
|  15 | Reserved |
|  14 | Reserved |
|  13 | Reserved |
|  12 | Reserved |
|  11 | Reserved |
|  10 | Reserved |
| 9 | Allow system use of LED1 |
| 8 | Allow system use of LED0 |
| 0-7 | Reserved |

The default value for the flags word is $XFXX (XX being reserved bits which can
have any value). This allows the system to take control of the two LEDs I0 and I1.

User code may clear any of the non-reserved bits to take full control of the appropriate
lines. 

**Note** that changing any reserved bits from their default values will result in 
undefined behaviour and possible data loss.

**Note** that, in the case of total system crash (i.e. a crash that is unrecoverable
without a hardware button-push reset), these bits will not be honored and the system 
will assume full control.

**Note** also that clearing these bits has no effect on the actual state of the relevant
lines, and user code should set the lines to a known state after setting this word.

### CPU Info (0x41C)

This four-byte value encodes the CPU type (3 bits indicating the family version number,
and 29 bits with the approximate multiplied speed measured at boot time).

Where multiple processors are present, this field will refer to the boot CPU.

## 2.3. Extension Function Pointer Table (EFPT)

**Start Address**: 0x420
**End Address**: 0x4FF
**Size**: 0xE0 (224 bytes, 56 pointers)

This area contains pointers to functions which are called by the
firmware and TRAP handlers to achieve various things. 

The purpose of this pointer table is to allow these functions
to be replaced by driver software. For example, the V9958 driver
replaces some of these functions in order to redirect output 
to the video console.

Driver writers can replace functions here in order to hook into
the firmware. The general rules are:

* The pointers can point anywhere, but the function that is pointed to **must** remain at that address!
* On entry to the function, the CPU will be in supervisor mode
* On entry to the function, the SP will reference the supervisor stack

Not all of these functions will be used by the firmware - some are 
designated as for program use (for example, a kernel may use them
to provide its own hooks).

User code **must not** call these functions directly - they 
must be accessed through the public TRAP functions!

| Address | Function |
|---|---|
| 0x420 | FW_PRINT - Print SZ to the default console. |
| 0x424 | FW_PRINTLN - Print SZ to the default console, followed by CRLF |
| 0x428 | FW_PRINTCHAR - Print a character to the default console |
| 0x42C | FW_HALT - Disable interrupts and halt |
| 0x430 | FW_SENDCHAR - Send a character via the default UART | 
| 0x434 | FW_RECVCHAR - Receive a character via the default UART |
| 0x438 | FW_CLRSCR - Clear the default console (where supported) |
| 0x43C | FW_MOVEXY - Move cursor to (X,Y) (see note 1) |
| 0x440 | FW_SETCURSOR - Show (D0.B > 0) or hide (D0.B == 0) the cursor |
| 0x444 | FW_CHECKCHAR - Determine whether a character is available on the default UART |
| 0x448 | FW_PROGRAM_LOADER - The firmware uses this to invoke the program loader (defaults to SD/Kermit) |
| 0x44C | FW_SD_INIT - Initialize SD Card |
| 0x450 | FW_SD_READ - Read from SD Card |
| 0x454 | FW_SD_WRITE - Write to SD Card |
| 0x458 | FW_SD_REG - Read SD Card register |
| 0x45C | FW_SPI_INIT - Intialize SPI subsystem |
| 0x460 | FW_SPI_ASSERT_CS - Assert SPI chip select 0 or 1 |
| 0x464 | FW_SPI_DEASSERT_CS - Deassert SPI chip select 0 or 1 |
| 0x468 | FW_SPI_TRANSFER_BYTE - Transfer (exchange) a byte |
| 0x46C | FW_SPI_TRANSFER_BUFFER - Transfer (exchange) N bytes to/from a buffer |
| 0x470 | FW_SPI_RECV_BYTE - Receive a byte |
| 0x474 | FW_SPI_RECV_BUFFER - Receive N bytes into a buffer |
| 0x478 | FW_SPI_SEND_BYTE - Send a byte |
| 0x47C | FW_SPI_SEND_BUFFER - Send N bytes from a buffer |
| 0x480 | FW_ATA_INIT - Initialize ATA PIO device |
| 0x484 | FW_ATA_READ - Read from ATA device |
| 0x488 | FW_ATA_WRITE - Write to ATA device |
| 0x48C | FW_ATA_IDENT - `IDENTIFY` ATA device |
| 0x490 | FW_PROG_EXIT - Vector used by library code to support the exit() function |
| 0x494 | FW_INPUTCHAR - Blocking read from default input device |
| 0x498 | FW_CHECKINPUT - Check if a character is available on default input device |

**Note 1**: FW_GOTOXY takes the coordinates to move to from D1.W. The high
byte is the X coordinate (Column) and the low byte is the Y coordinate (Row).

**Note 2**: The SD, SPI and ATA routines arguments, modifies and returns are the same as for the TRAPs they 
underlie unless otherwise noted. See section 1 for details.

Arguments, modifies and other information for these functions are the same
as for the TRAP functions they implement. If replacing them, you **must**
adhere to the same interface. The reference implementations can be found in
`bootstrap.S`, `trap14.S` and `sdcard/syscalls_asm.S`.

**Note** that all of these are allowed to block! 

## 2.4. Video IO Data Area (VDA)

**Start Address**: 0x500
**End Address**: 0x117F
**Size**: 0xC80 (3200 bytes)

This area is reserved for use by video subsystems. The specific layout
is dependent on the video subsystem in use.

For example, this area may contain a framebuffer along with
variables and data required by a video driver.

TODO document layout when video is V9958!

## 2.5. Firmware Reserved Area 1 (Internal)

**Start Address**: 0x1180
**End Address**: 0x17FF
**Size**: 0x680 (1664 bytes)

This area is reserved for future Firmware expansion.

## 2.6. Firmware Reserved Area 2 (BSS)

**Start Address**: 0x1800
**End Address**: 0x1FFF
**Size**: 0x800 (2048 bytes)

This area is reserved for the firmware's BSS section. The content
and layout of this area may change without notice.

# 3. Character Devices

## 3.1 General Information

The system provides support for up to 16 character devices which are
accessed through the relevant routines in TRAP 14.

Any UART devices detected during firmware initialization will 
automatically have such devices created for them. The remainder are
available for user use.

## 3.2. The `CHAR_DEVICE` structure

The `CHAR_DEVICE` structure is currently 32 bytes:

| Offset | Size | Contains |
|---|---|---|
| 0x0 |  0x4 | Data required by the functions (e.g. base address) |
| 0x4 |  0x4 | CHECKCHAR function pointer |
| 0x8 |  0x4 | RECVCHAR function pointer |
| 0xC |  0x4 | SENDCHAR function pointer |
| 0x10 |  0x4 | Reserved for future use |
| 0x14 |  0x4 | Reserved for future use |
| 0x18 |  0x4 | DEVICE_CTRL function pointer |
| 0x1C |  0x2 | Capability flags |
| 0x1E |  0x1 | Additional device-specific flags |
| 0x1F |  0x1 | Device type |

### 3.2.1 Capability Flags

The capability flags are a work in progress, and are currently ignored.

### 3.2.2 Device Types

The device types currently defined by the system are:

| Type | Description |
|---|---|
| 0x01 | MFP in-built UART |
| 0x02 | DUART Port A |
| 0x03 | DUART Port B |

## 3.3. Device function calling conventions

> **Note** It is legal to call device functions directly from user codes. They 
should be designed accordingly. The system TRAPs to call them are
provided for convenience only, and device functions should not assume
the CPU will be in supervisor mode when they are called.

All the device functions receive a pointer to their `CHAR_DEVICE` 
structure in A0. `D0` is used for the return value where applicable.

The calling convention (other than the pointer to the device structure)
is the same as the `CHECKCHAR`, `RECVCHAR` and `SENDCHAR` functions
in TRAP 14.

If the device routines are to be directly called from (for example) C
then a wrapper will be required to manage moving arguments from the
stack to the appropriate registers.

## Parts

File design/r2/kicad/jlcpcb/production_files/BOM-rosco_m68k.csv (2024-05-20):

Comment | Designator | Footprint | LCSC
100nF | C10,C12,C13,C22,C24,C25,C26,C27,C28,C29,C3,C30,C31,C32,C4,C5,C6,C7,C8,C9 | C_0603_1608Metric | C14663
100nF | C33,C34,C35,C36,C37,C38 | C_0402_1005Metric | C1525
7pF | C1,C2 | C_0603_1608Metric | C1682
4.7uF | C16,C20,C23,C39,C40 | C_0603_1608Metric | C19666
1K | R1,R13,R14,R2,R33 | R_0603_1608Metric | C21190
1K2 | R21 | R_0603_1608Metric | C22765
12K | R30 | R_0603_1608Metric | C22790
270R | R28 | R_0603_1608Metric | C22966
4K7 | R10,R12,R15,R16,R17,R18,R3,R31,R32,R7,R8,R9 | R_0603_1608Metric | C23162
5.1K | R4,R5 | R_0603_1608Metric | C23186
10K | R11,R19 | R_0603_1608Metric | C25804
FT2232HL | IC12 | LQFP-64_10x10mm_P0.5mm | C27882
AP2127K-3.3 | U6 | SOT-23-5 | C2865116
USB_C_Receptacle_PowerOnly_6P | J10 | USB_C_Receptacle_Palconn_UTC16-G | C2927039
12MHz | Y2 | Crystal_SMD_HC49-SD | C2975357
27pF | C41,C42 | C_0603_1608Metric | C376778
2K | R20,R22,R23,R6 | R_0402_1005Metric | C4109
TPS22929D | IC13 | SOT-23-6 | C415177
2K2 | R27 | R_0603_1608Metric | C4190
BLM18HE152SN1D | FB1,FB2,FB3 | L_0603_1608Metric | C596494
SN74LVC2G17 | IC10,IC11,IC8,IC9 | SOT-23-6 | C7394037
RED | LED5,LED6,LED7,LED8 | LED_0805_2012Metric | C84256

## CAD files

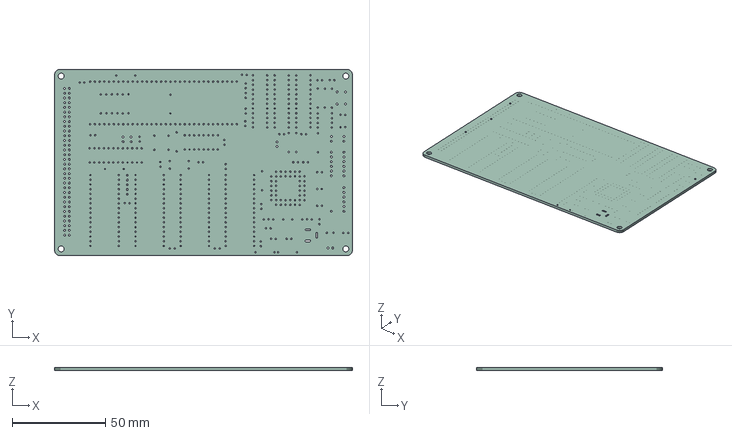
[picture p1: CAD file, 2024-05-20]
design/r2/kicad/rosco_m68k.step
160.0 x 100.0 x 1.60 mm

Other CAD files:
design/r2/kicad/rosco_m68k.stl

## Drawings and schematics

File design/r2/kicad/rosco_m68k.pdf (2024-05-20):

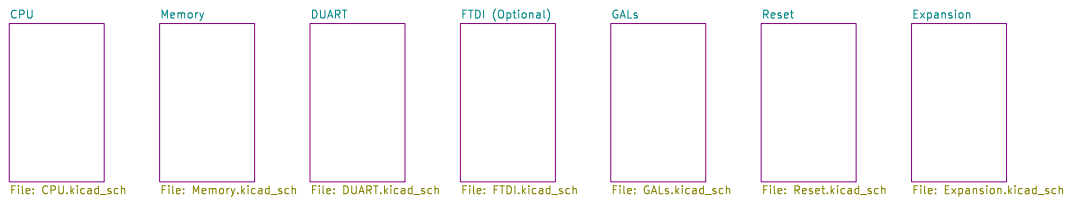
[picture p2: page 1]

Id: 1/8 Title: ROSCO_M68K GENERAL PURPOSE MC68010 COMPUTER

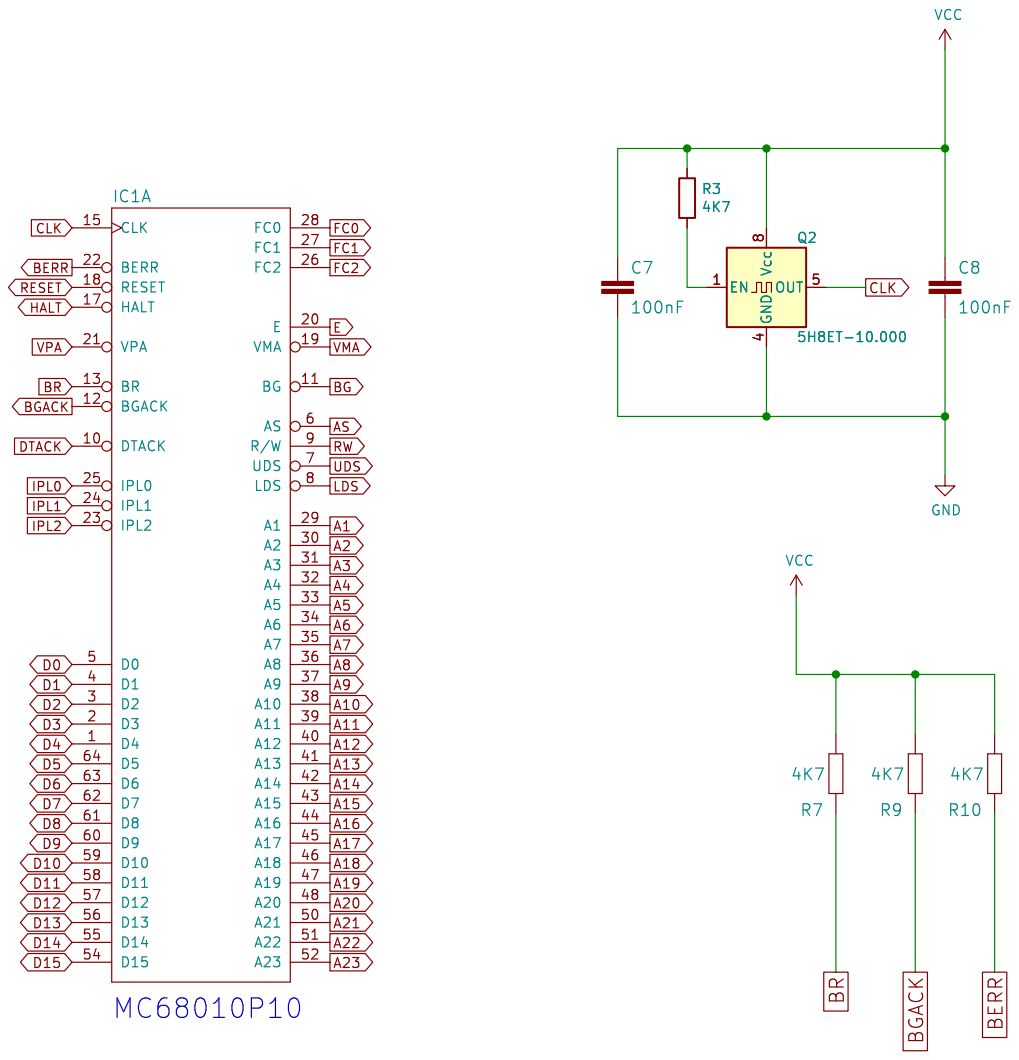
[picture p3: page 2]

Id: 2/8 Title: ROSCO_M68K GENERAL PURPOSE MC68010 COMPUTER

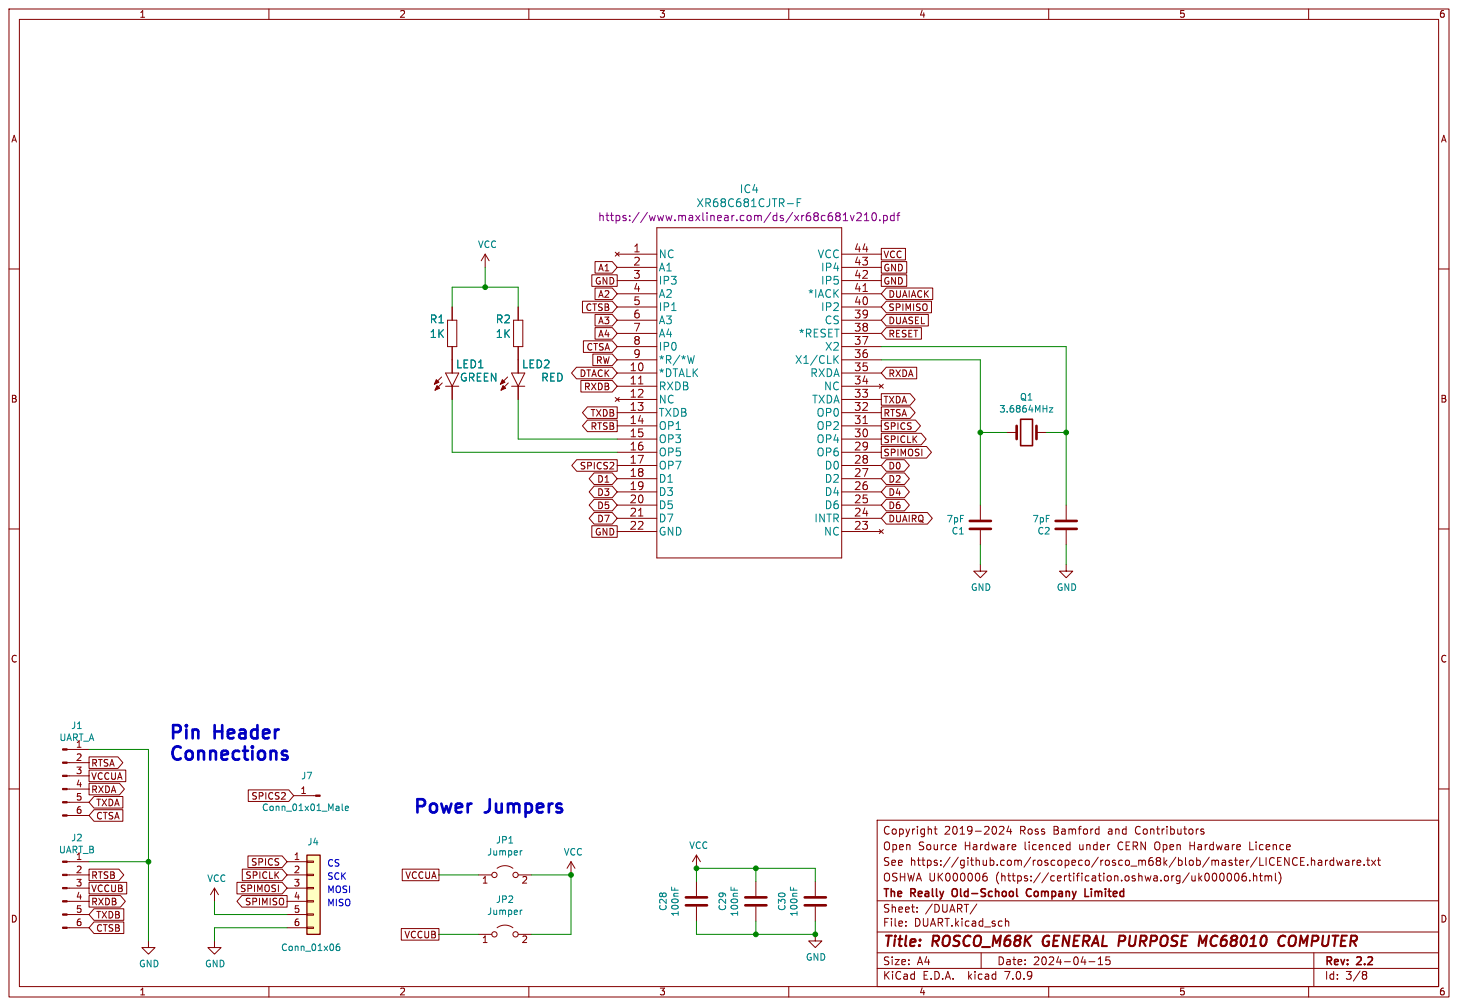
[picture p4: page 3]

https://www.maxlinear.com/ds/xr68c681v210.pdf

A3A1 CTSB
TXDA RXDA RXDB GND

Id: 3/8 Title: ROSCO_M68K GENERAL PURPOSE MC68010 COMPUTER

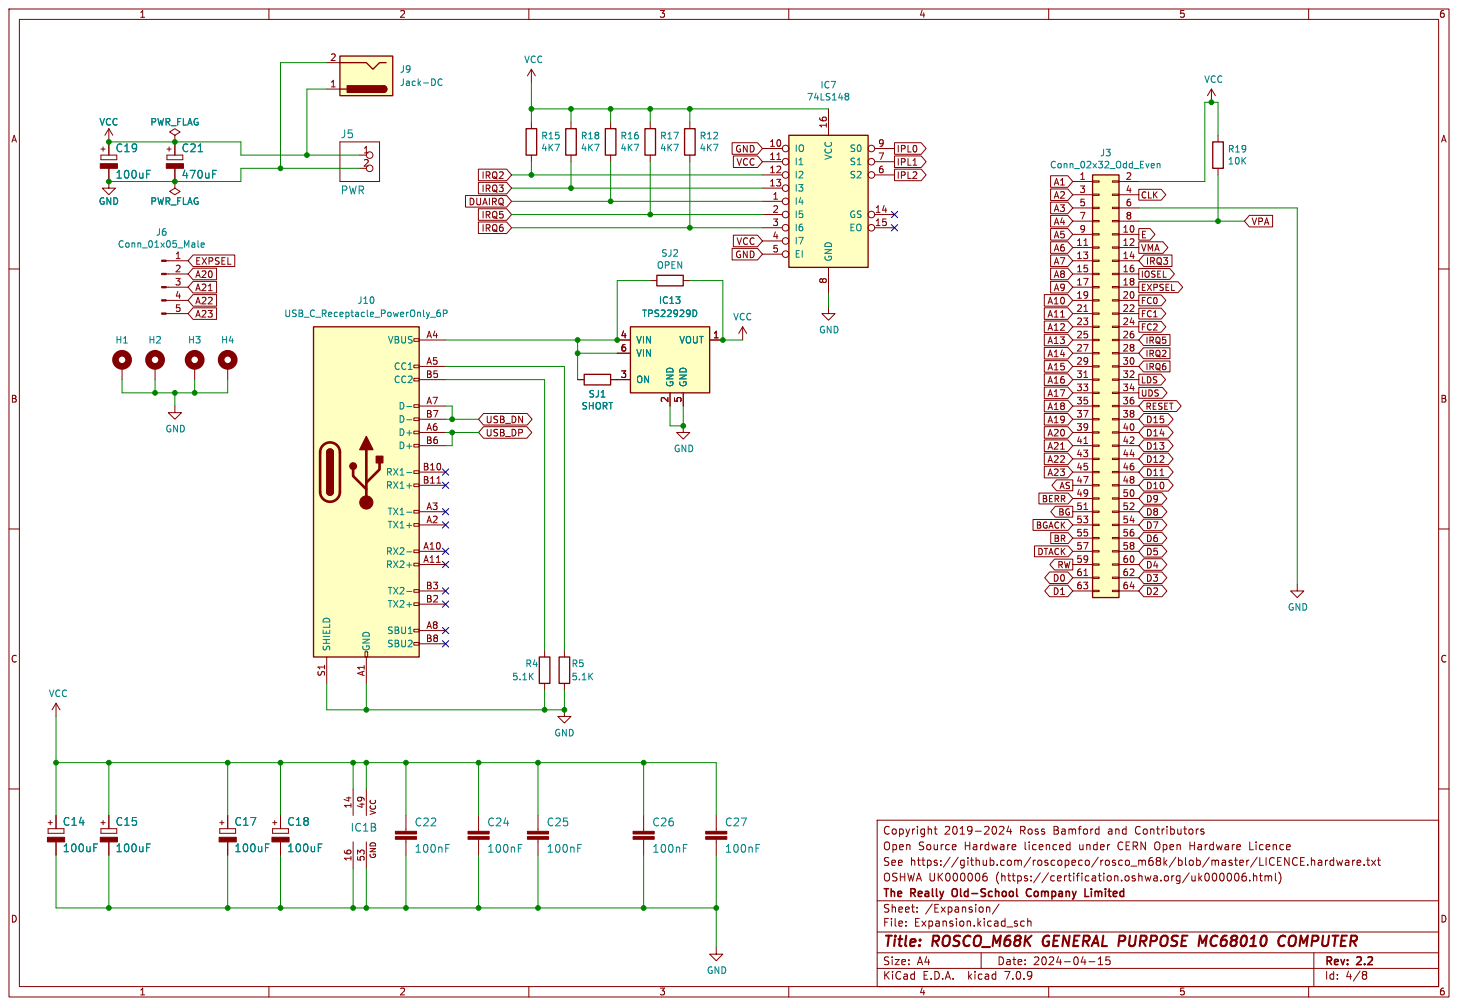
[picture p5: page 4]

Id: 4/8 Title: ROSCO_M68K GENERAL PURPOSE MC68010 COMPUTER

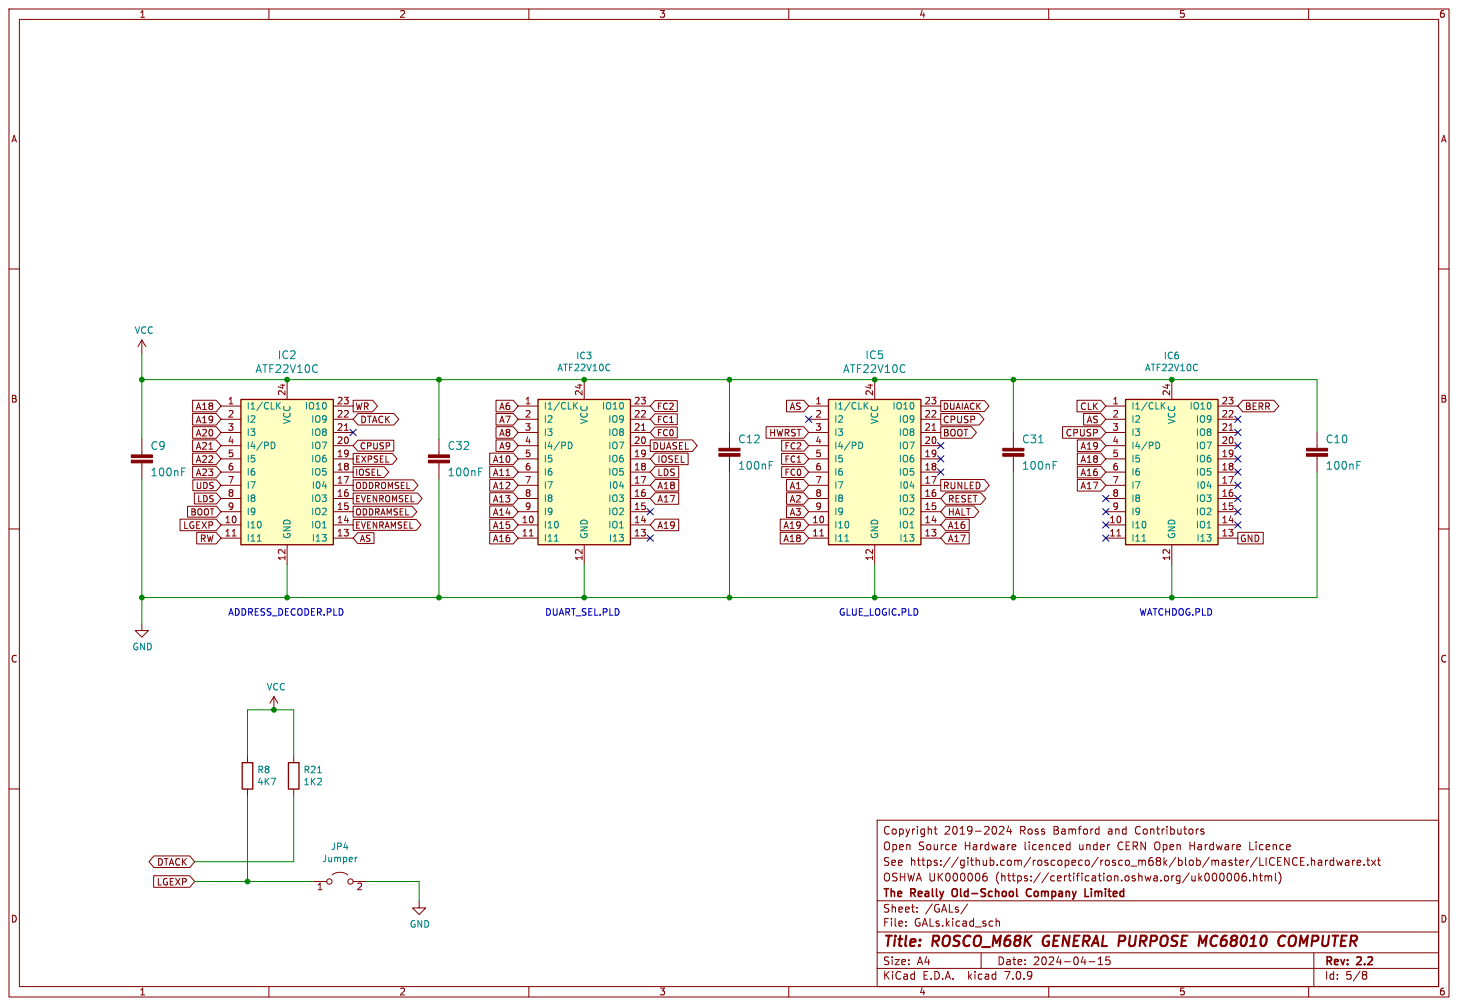
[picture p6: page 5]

Id: 5/8 Title: ROSCO_M68K GENERAL PURPOSE MC68010 COMPUTER

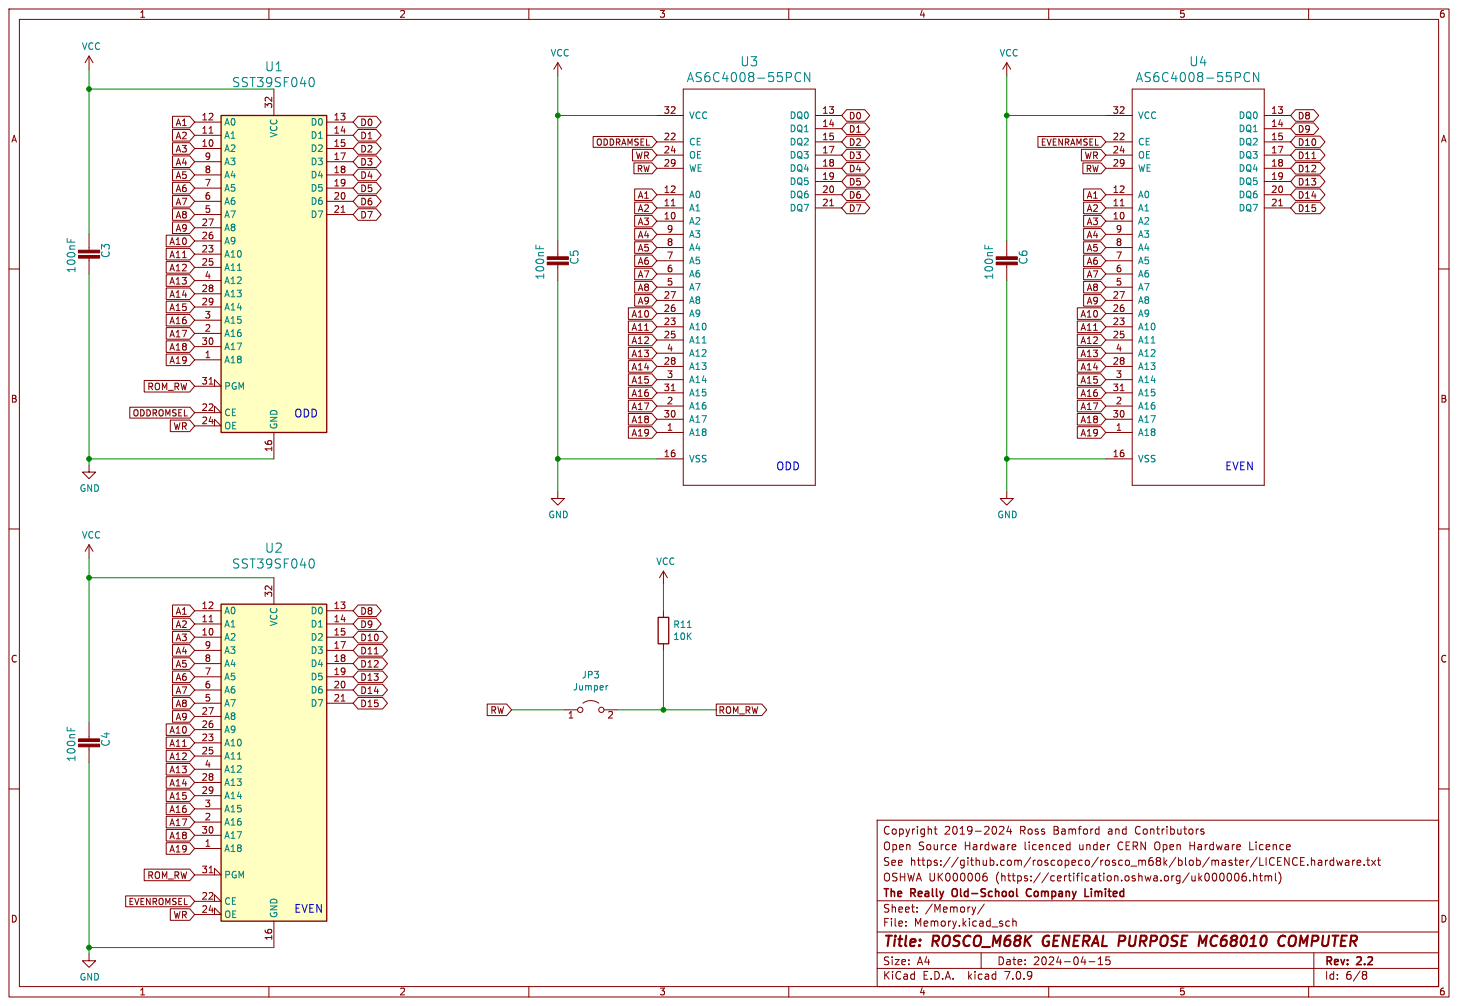
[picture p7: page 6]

Id: 6/8 Title: ROSCO_M68K GENERAL PURPOSE MC68010 COMPUTER

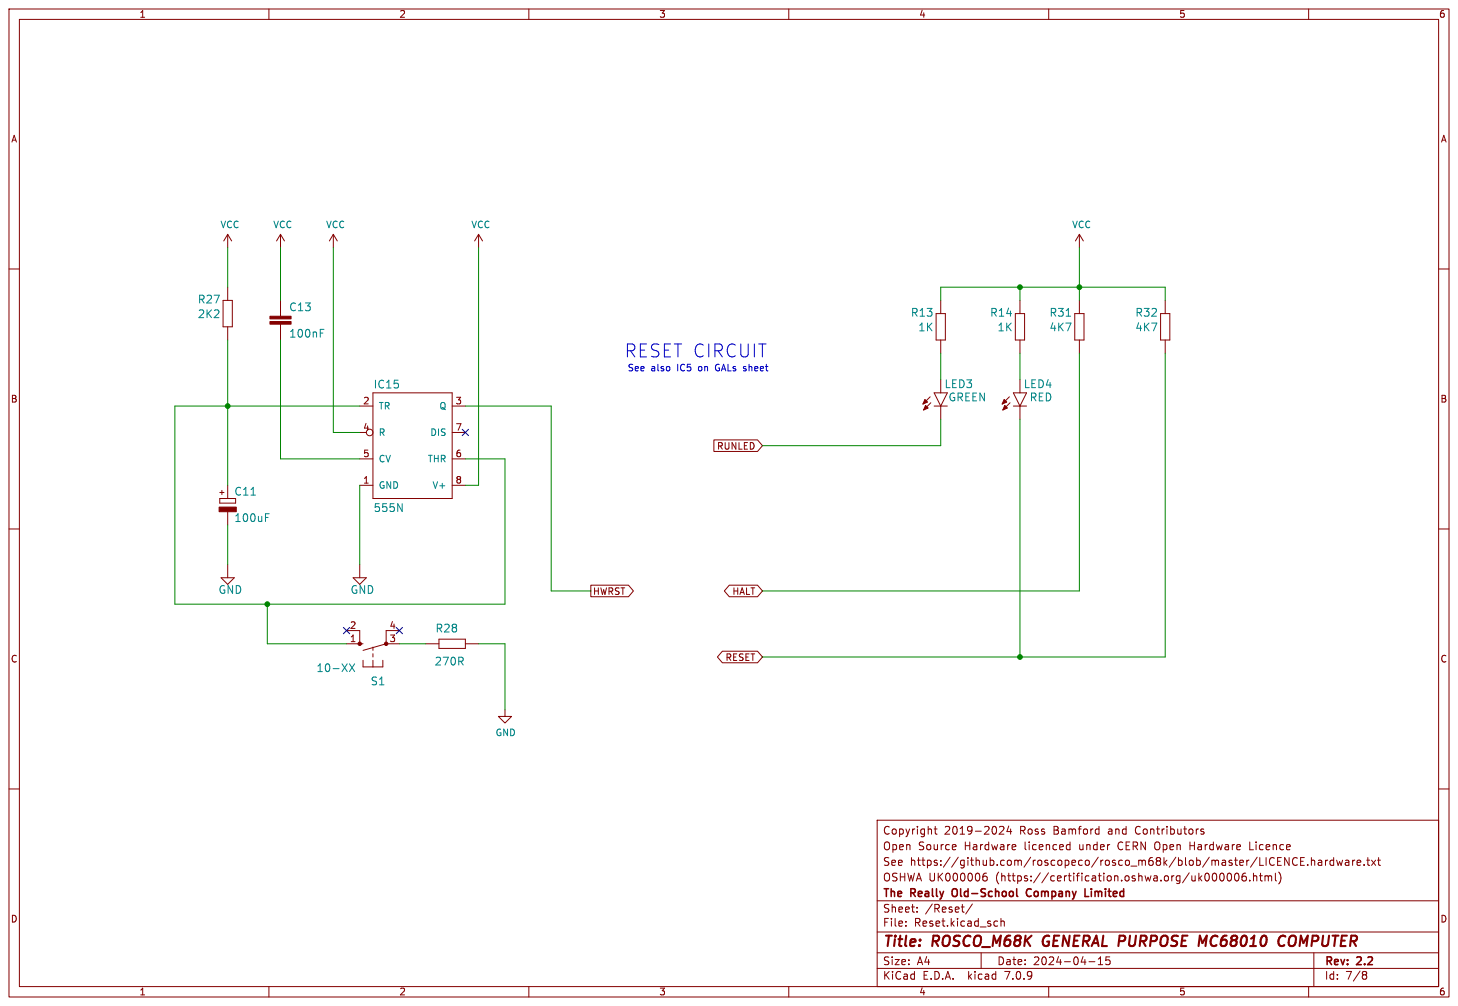
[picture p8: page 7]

HALT RESET HWRSTRESET CIRCUIT

See also IC5 on GALs sheet

Id: 7/8 Title: ROSCO_M68K GENERAL PURPOSE MC68010 COMPUTER

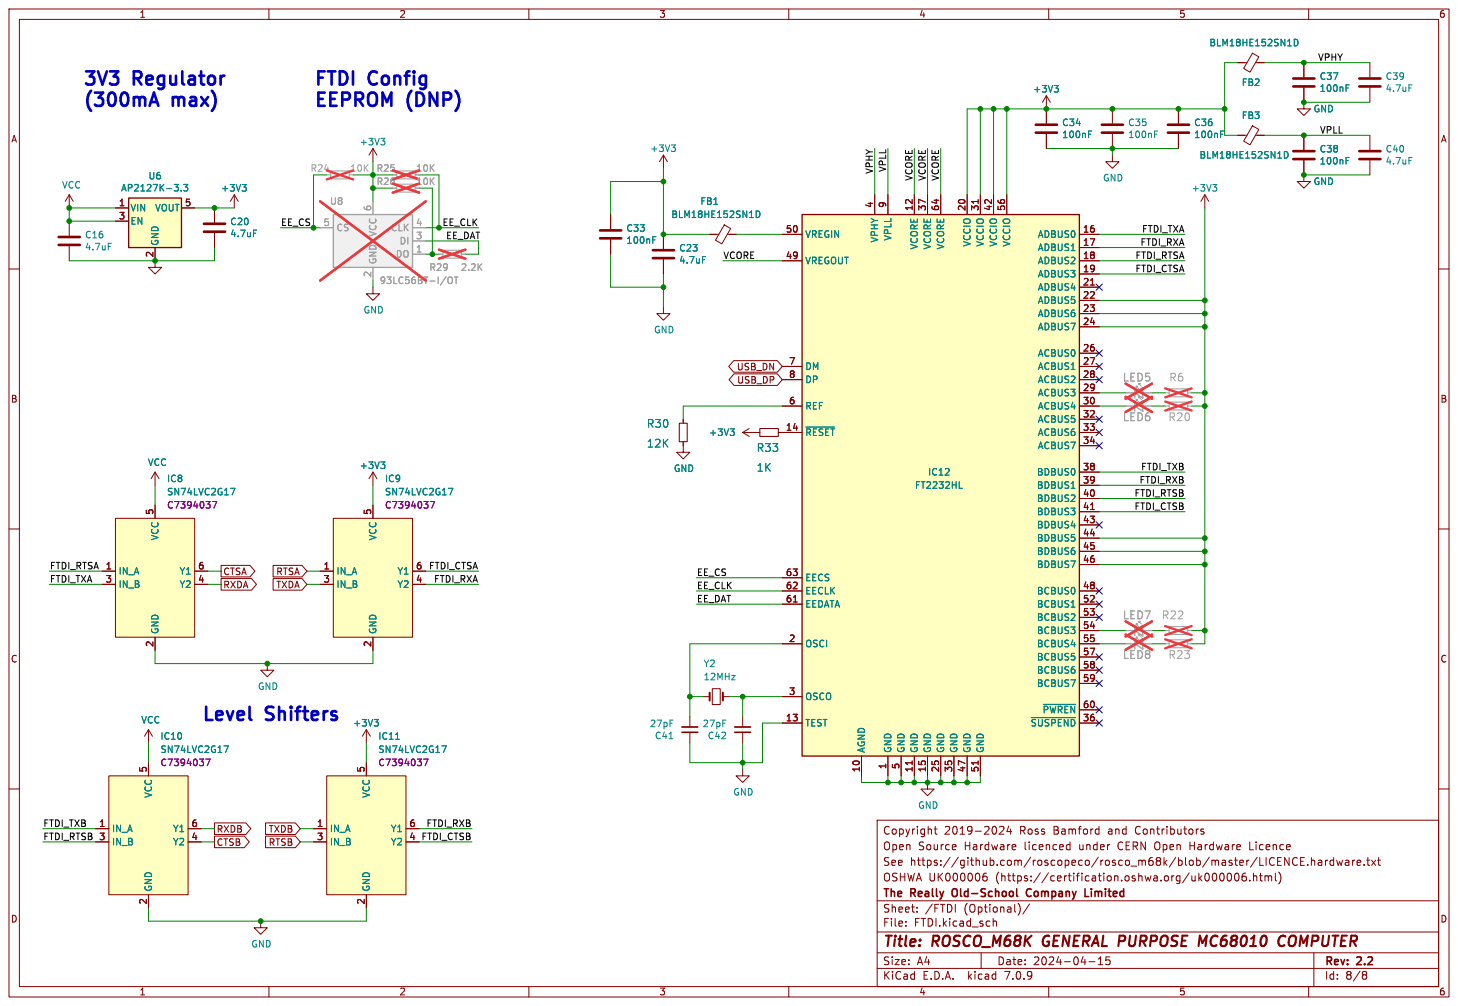
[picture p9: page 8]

2 EN 3 VOUT 5 U6 AP2127K-3.3 R26 10K DO 1 GND

1 AGND 10 GND 11 VCORE 12 TEST 13 ~{RESET} 14 GND 15 ADBUS0 16 ADBUS1 17 ADBUS2 18 ADBUS3 19 OSCI 2 VCCIO 20 ADBUS4 21 ADBUS5 22 ADBUS6 23 ADBUS7 24 GND 25 ACBUS0 26 ACBUS1 27 ACBUS2 28 ACBUS3 29 OSCO 3 ACBUS4 30 VCCIO 31 ACBUS5 32 ACBUS6 33 ACBUS7 34 GND 35

4 BDBUS2 40 BDBUS3 41 VCCIO 42 BDBUS4 43 BDBUS5 44 BDBUS6 45 BDBUS7 46 GND 47 BCBUS0 48 VREGOUT 49 GND

5 VREGIN 50 GND 51 BCBUS1 52 BCBUS2 53 BCBUS3 54 BCBUS4 55 VCCIO 56 BCBUS5 57 BCBUS6 58 BCBUS7 59 REF 6 ~{PWREN}60 EEDATA 61 EECLK 62 EECS 63 VCORE 64 DM 7 DP 8 VPLL

2 DI 3 CLK 4 CS 5 VCC

Id: 8/8 Title: ROSCO_M68K GENERAL PURPOSE MC68010 COMPUTER

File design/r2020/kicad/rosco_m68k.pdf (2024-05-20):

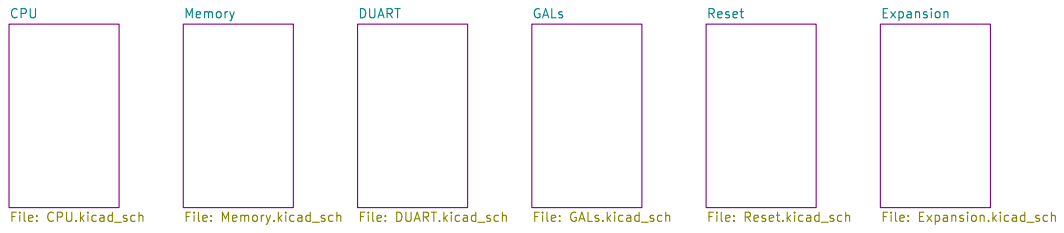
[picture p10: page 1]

Id: 1/7 Title: ROSCO_M68K CLASSIC MC68020 EDITION

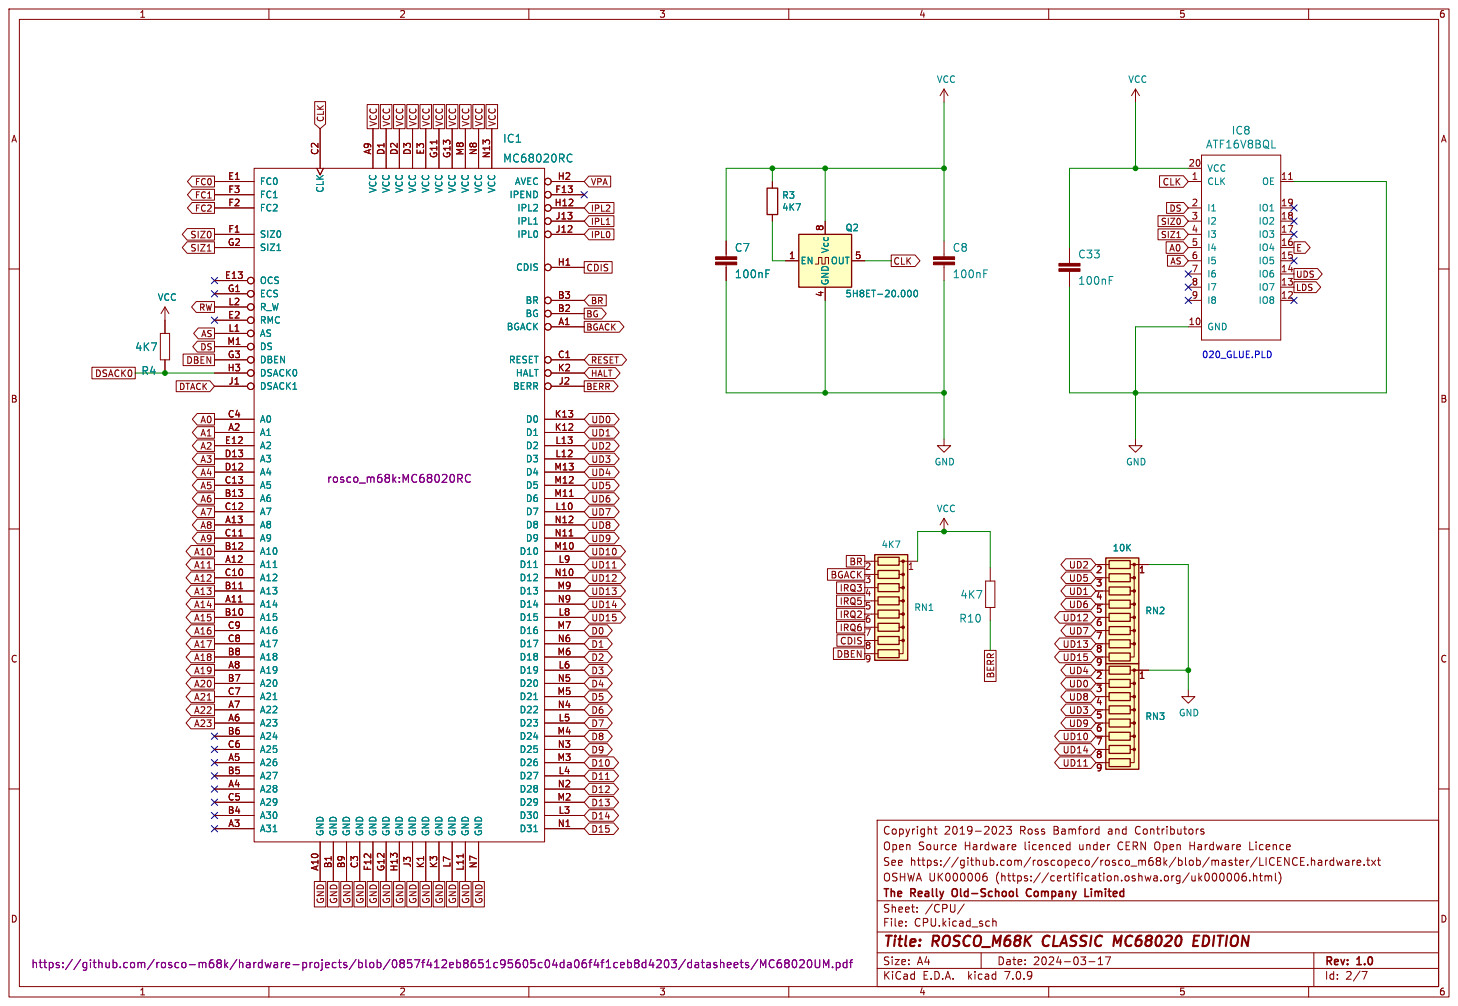
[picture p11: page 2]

VPA VCC VCC VCC

D14 D9 D1 D4 D5 D2 D0 UD14 D3 UD15 UD11 UD6 UD12 UD8 UD10 UD9 UD13 UD7 GND GND GND GND GND

https://github.com/rosco-m68k/hardware-projects/blob/0857f412eb8651c95605c04da06f4f1ceb8d4203/datasheets/MC68020UM.pdf GND

Id: 2/7 Title: ROSCO_M68K CLASSIC MC68020 EDITION

https://github.com/rosco-m68k/hardware-projects/blob/0857f412eb8651c95605c04da06f4f1ceb8d4203/datasheets/MC68020UM.pdf

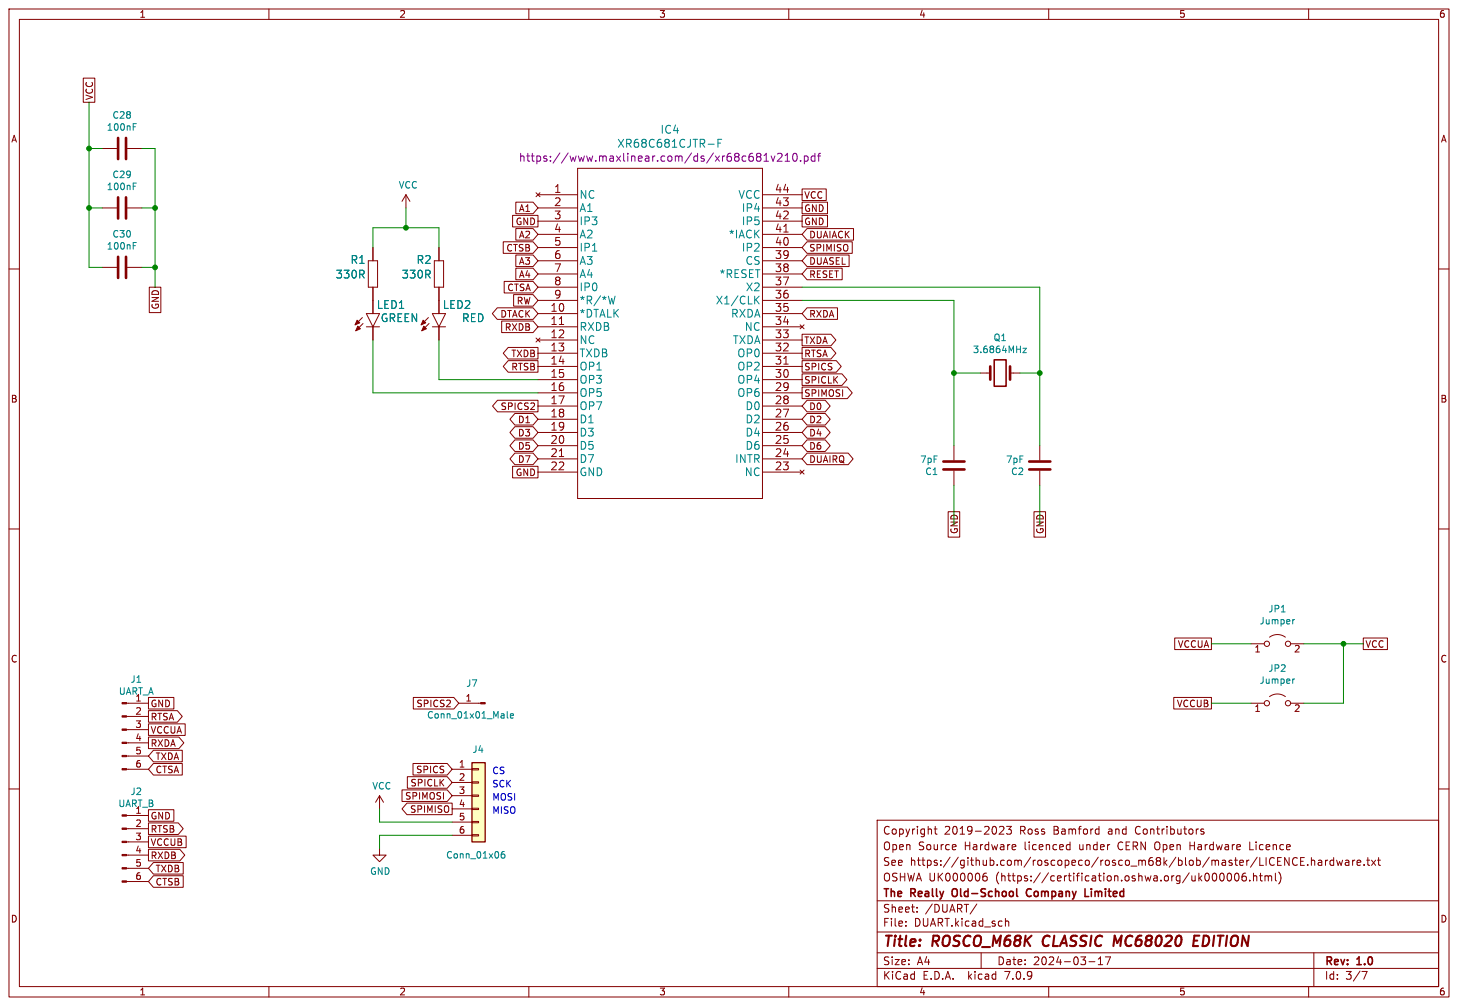
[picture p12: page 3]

Id: 3/7 Title: ROSCO_M68K CLASSIC MC68020 EDITION

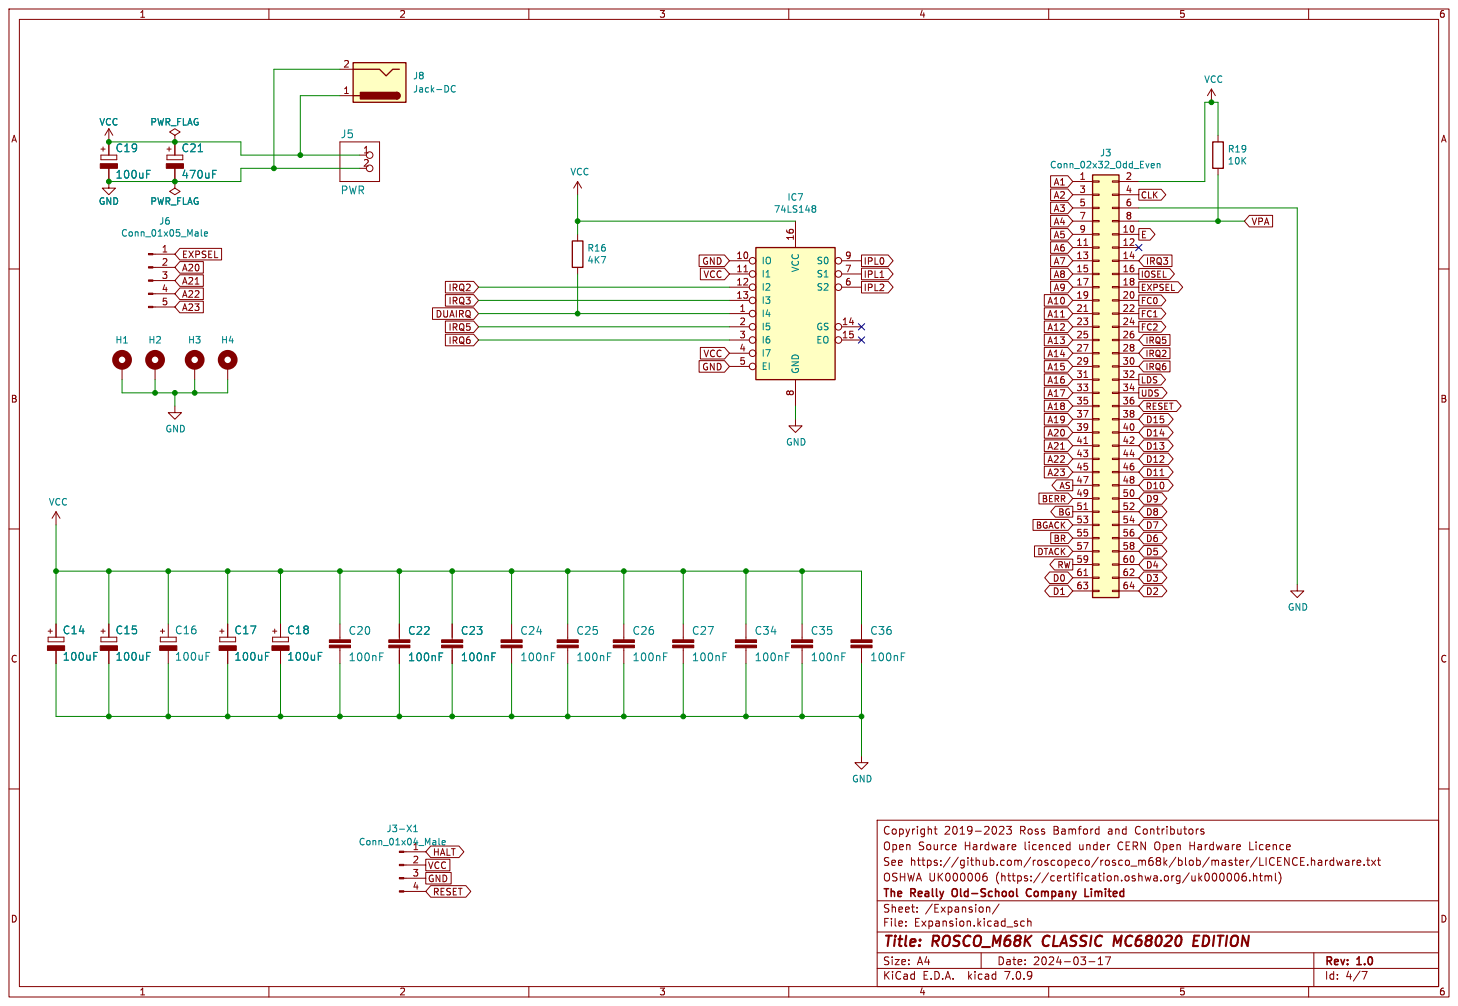
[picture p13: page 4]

Id: 4/7 Title: ROSCO_M68K CLASSIC MC68020 EDITION


Id: 5/7 Title: ROSCO_M68K CLASSIC MC68020 EDITION


Id: 6/7 Title: ROSCO_M68K CLASSIC MC68020 EDITION


See also IC14 on GALs sheet RESET CIRCUIT

Id: 7/7 Title: ROSCO_M68K CLASSIC MC68020 EDITION

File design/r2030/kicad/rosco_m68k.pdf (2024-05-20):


Id: 1/7 Title: ROSCO_M68K CLASSIC MC68030 EDITION


Id: 2/7 Title: ROSCO_M68K CLASSIC MC68030 EDITION


https://www.maxlinear.com/ds/xr68c681v210.pdf LED2RED

D0 D6 D4 SPIMOSI CTSB CTSA RW

VCCUA RESET SCK CSMISO MOSI

Id: 3/7 Title: ROSCO_M68K CLASSIC MC68030 EDITION


Id: 4/7 Title: ROSCO_M68K CLASSIC MC68030 EDITION


A9 EXPSEL ODDROMSEL EVENROMSEL ODDRAMSEL AS

Id: 5/7 Title: ROSCO_M68K CLASSIC MC68030 EDITION


Id: 6/7 Title: ROSCO_M68K CLASSIC MC68030 EDITION


See also IC14 on GALs sheet RESET CIRCUIT

Id: 7/7 Title: ROSCO_M68K CLASSIC MC68030 EDITION

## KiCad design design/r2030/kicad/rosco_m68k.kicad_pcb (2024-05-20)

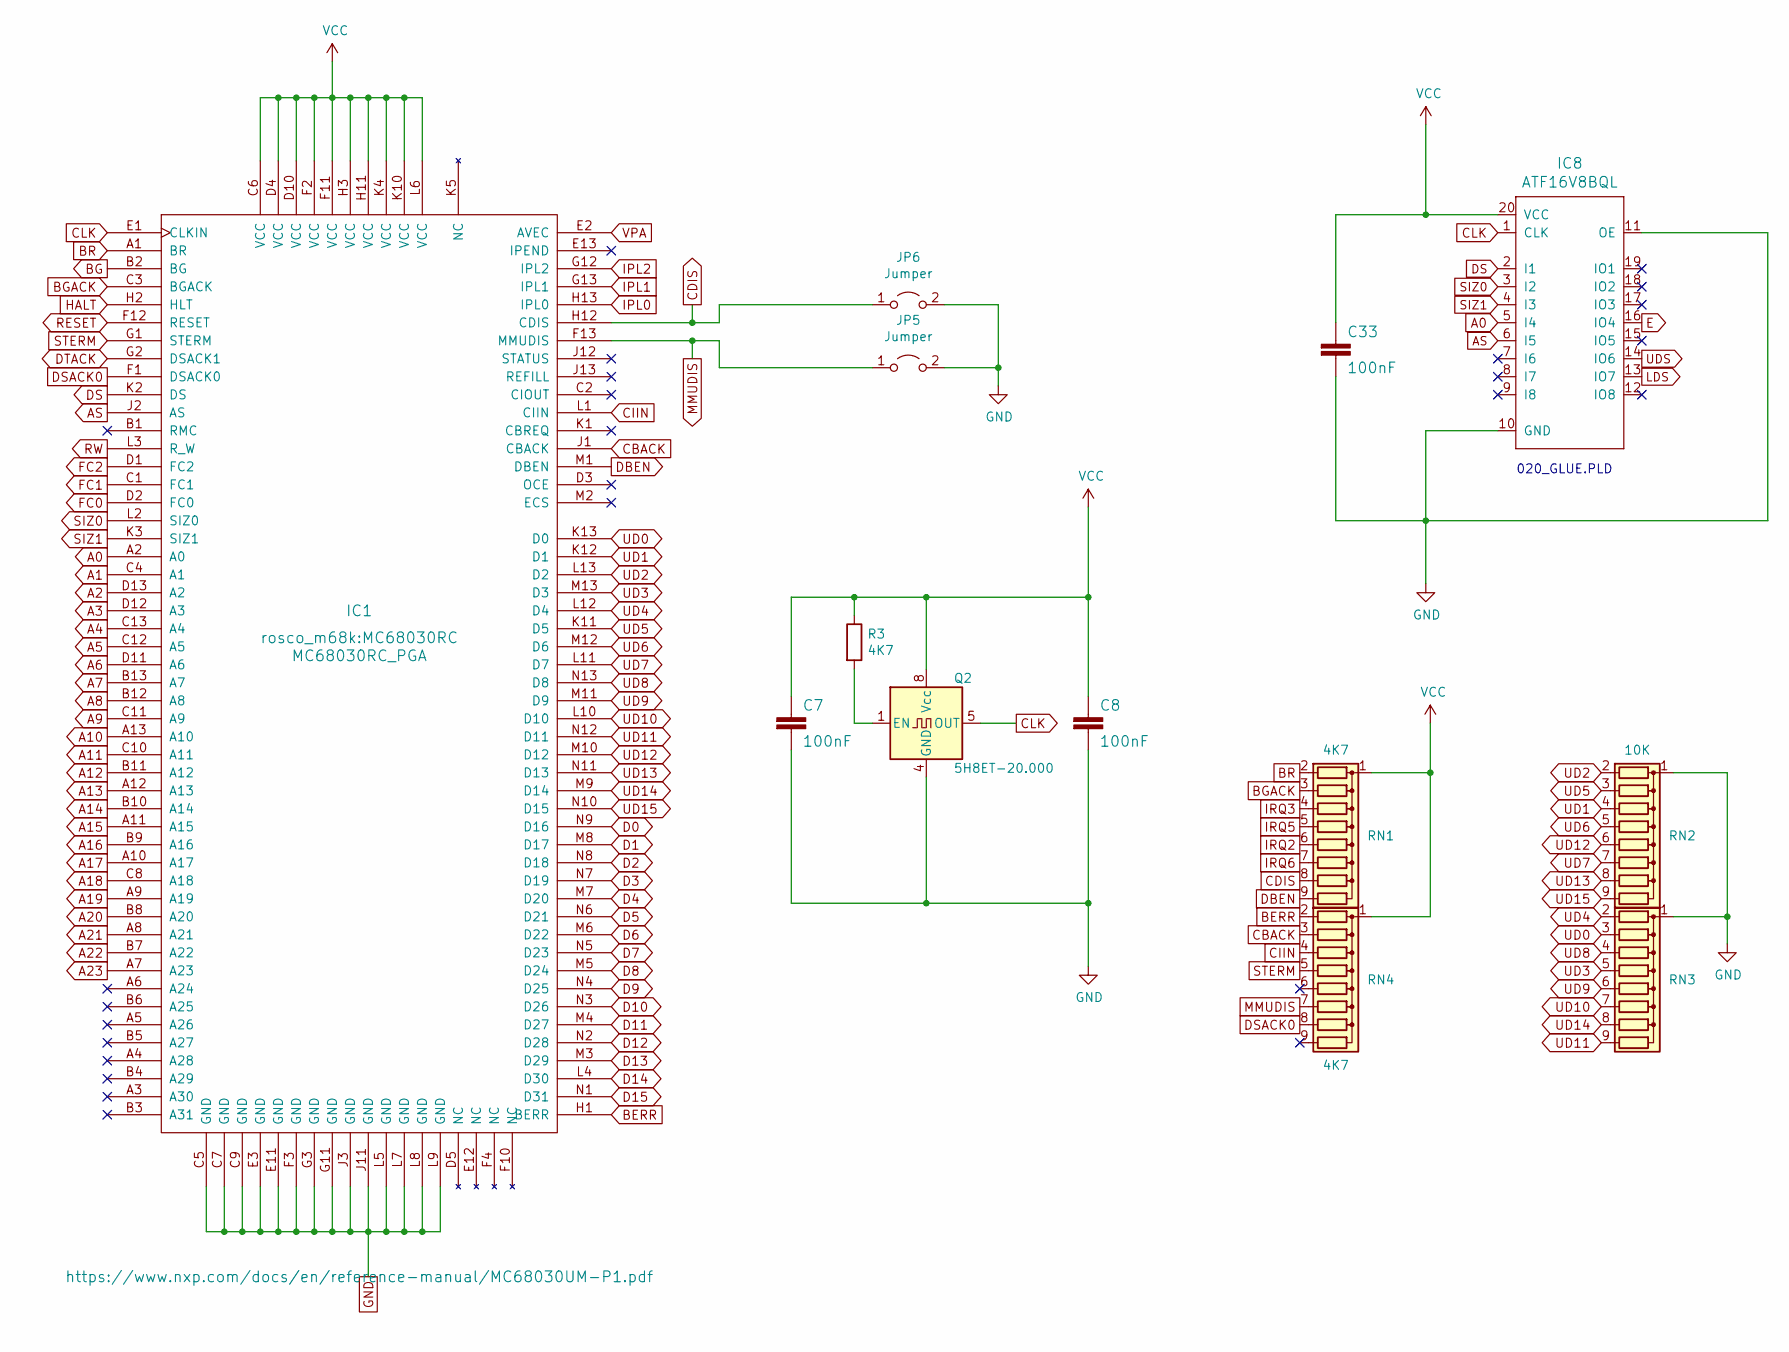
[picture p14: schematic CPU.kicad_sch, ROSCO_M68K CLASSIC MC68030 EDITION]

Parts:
C7, C8, C33: 100nF; C2.5-3
IC1: MC68030RC_PGA; MC68030RC
IC8: ATF16V8BQL; DIL20
JP5, JP6: Jumper; 1X02
Q2: 5H8ET-20.000; Oscillator_DIP-8
R3: 4K7; 0207_10
RN1, RN4: 4K7; R_Array_SIP9
RN2: 10K; R_Array_SIP9
RN3: R_Network08; R_Array_SIP9

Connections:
A0: IC1.A2 (A0), IC8.5 (I4)
A1: IC1.C4 (A1); also elsewhere on the board
A2: IC1.D13 (A2); also elsewhere on the board
A3: IC1.D12 (A3); also elsewhere on the board
A4: IC1.C13 (A4); also elsewhere on the board
A5: IC1.C12 (A5); also elsewhere on the board
A6: IC1.D11 (A6); also elsewhere on the board
A7: IC1.B13 (A7); also elsewhere on the board
A8: IC1.B12 (A8); also elsewhere on the board
A9: IC1.C11 (A9); also elsewhere on the board
A10: IC1.A13 (A10); also elsewhere on the board
A11: IC1.C10 (A11); also elsewhere on the board
A12: IC1.B11 (A12); also elsewhere on the board
A13: IC1.A12 (A13); also elsewhere on the board
A14: IC1.B10 (A14); also elsewhere on the board
A15: IC1.A11 (A15); also elsewhere on the board
A16: IC1.B9 (A16); also elsewhere on the board
A17: IC1.A10 (A17); also elsewhere on the board
A18: IC1.C8 (A18); also elsewhere on the board
A19: IC1.A9 (A19); also elsewhere on the board
A20: IC1.B8 (A20); also elsewhere on the board
A21: IC1.A8 (A21); also elsewhere on the board
A22: IC1.B7 (A22); also elsewhere on the board
A23: IC1.A7 (A23); also elsewhere on the board
AS: IC1.J2 (AS), IC8.6 (I5); also elsewhere on the board
BERR: IC1.H1 (BERR), RN4.2 (R1); also elsewhere on the board
BG: IC1.B2 (BG); also elsewhere on the board
BGACK: IC1.C3 (BGACK), RN1.3 (R2); also elsewhere on the board
BR: IC1.A1 (BR), RN1.2 (R1); also elsewhere on the board
CBACK: IC1.J1 (CBACK), RN4.3 (R2)
CDIS: IC1.H12 (CDIS), JP6.1 (A), RN1.8 (R7)
CIIN: IC1.L1 (CIIN), RN4.4 (R3)
CLK: IC1.E1 (CLKIN), IC8.1 (CLK), Q2.5 (OUT); also elsewhere on the board
D0: IC1.N9 (D16); also elsewhere on the board
D1: IC1.M8 (D17); also elsewhere on the board
D2: IC1.N8 (D18); also elsewhere on the board
D3: IC1.N7 (D19); also elsewhere on the board
D4: IC1.M7 (D20); also elsewhere on the board
D5: IC1.N6 (D21); also elsewhere on the board
D6: IC1.M6 (D22); also elsewhere on the board
D7: IC1.N5 (D23); also elsewhere on the board
D8: IC1.M5 (D24); also elsewhere on the board
D9: IC1.N4 (D25); also elsewhere on the board
D10: IC1.N3 (D26); also elsewhere on the board
D11: IC1.M4 (D27); also elsewhere on the board
D12: IC1.N2 (D28); also elsewhere on the board
D13: IC1.M3 (D29); also elsewhere on the board
D14: IC1.L4 (D30); also elsewhere on the board
D15: IC1.N1 (D31); also elsewhere on the board
DBEN: IC1.M1 (DBEN), RN1.9 (R8)
DS: IC1.K2 (DS), IC8.2 (I1)
DSACK0: IC1.F1 (DSACK0), RN4.8 (R7)
DTACK: IC1.G2 (DSACK1); also elsewhere on the board
E: IC8.16 (IO4); also elsewhere on the board
FC0: IC1.D2 (FC0); also elsewhere on the board
FC1: IC1.C1 (FC1); also elsewhere on the board
FC2: IC1.D1 (FC2); also elsewhere on the board
GND: C7.2, C8.2, C33.2, IC1.C5 (GND), IC1.C7 (GND), IC1.C9 (GND), IC1.E3 (GND), IC1.E11 (GND), IC1.F3 (GND), IC1.G3 (GND), IC1.G11 (GND), IC1.J3 (GND), IC1.J11 (GND), IC1.L5 (GND), IC1.L7 (GND), IC1.L8 (GND), IC1.L9 (GND), IC8.10 (GND), IC8.11 (OE), JP5.2 (B), JP6.2 (B), Q2.4 (GND), RN2.1 (common), RN3.1 (common); also elsewhere on the board
HALT: IC1.H2 (HLT); also elsewhere on the board
IPL0: IC1.H13 (IPL0); also elsewhere on the board
IPL1: IC1.G13 (IPL1); also elsewhere on the board
IPL2: IC1.G12 (IPL2); also elsewhere on the board
IRQ2: RN1.6 (R5); also elsewhere on the board
IRQ3: RN1.4 (R3); also elsewhere on the board
IRQ5: RN1.5 (R4); also elsewhere on the board
IRQ6: RN1.7 (R6); also elsewhere on the board
LDS: IC8.13 (IO7); also elsewhere on the board
MMUDIS: IC1.F13 (MMUDIS), JP5.1 (A), RN4.7 (R6)
unnamed: Q2.1 (EN), R3.2
RESET: IC1.F12 (RESET); also elsewhere on the board
RW: IC1.L3 (R_W); also elsewhere on the board
SIZ0: IC1.L2 (SIZ0), IC8.3 (I2)
SIZ1: IC1.K3 (SIZ1), IC8.4 (I3)
STERM: IC1.G1 (STERM), RN4.5 (R4)
UD0: IC1.K13 (D0), RN3.3 (R2)
UD1: IC1.K12 (D1), RN2.4 (R3)
UD2: IC1.L13 (D2), RN2.2 (R1)
UD3: IC1.M13 (D3), RN3.5 (R4)
UD4: IC1.L12 (D4), RN3.2 (R1)
UD5: IC1.K11 (D5), RN2.3 (R2)
UD6: IC1.M12 (D6), RN2.5 (R4)
UD7: IC1.L11 (D7), RN2.7 (R6)
UD8: IC1.N13 (D8), RN3.4 (R3)
UD9: IC1.M11 (D9), RN3.6 (R5)
UD10: IC1.L10 (D10), RN3.7 (R6)
UD11: IC1.N12 (D11), RN3.9 (R8)
UD12: IC1.M10 (D12), RN2.6 (R5)
UD13: IC1.N11 (D13), RN2.8 (R7)
UD14: IC1.M9 (D14), RN3.8 (R7)
UD15: IC1.N10 (D15), RN2.9 (R8)
UDS: IC8.14 (IO6); also elsewhere on the board
VCC: C7.1, C8.1, C33.1, IC1.C6 (VCC), IC1.D4 (VCC), IC1.D10 (VCC), IC1.F2 (VCC), IC1.F11 (VCC), IC1.H3 (VCC), IC1.H11 (VCC), IC1.K4 (VCC), IC1.K10 (VCC), IC1.L6 (VCC), IC8.20 (VCC), Q2.8 (Vcc), R3.1, RN1.1 (common), RN4.1 (common); also elsewhere on the board
VPA: IC1.E2 (AVEC); also elsewhere on the board

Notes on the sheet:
020_GLUE.PLD

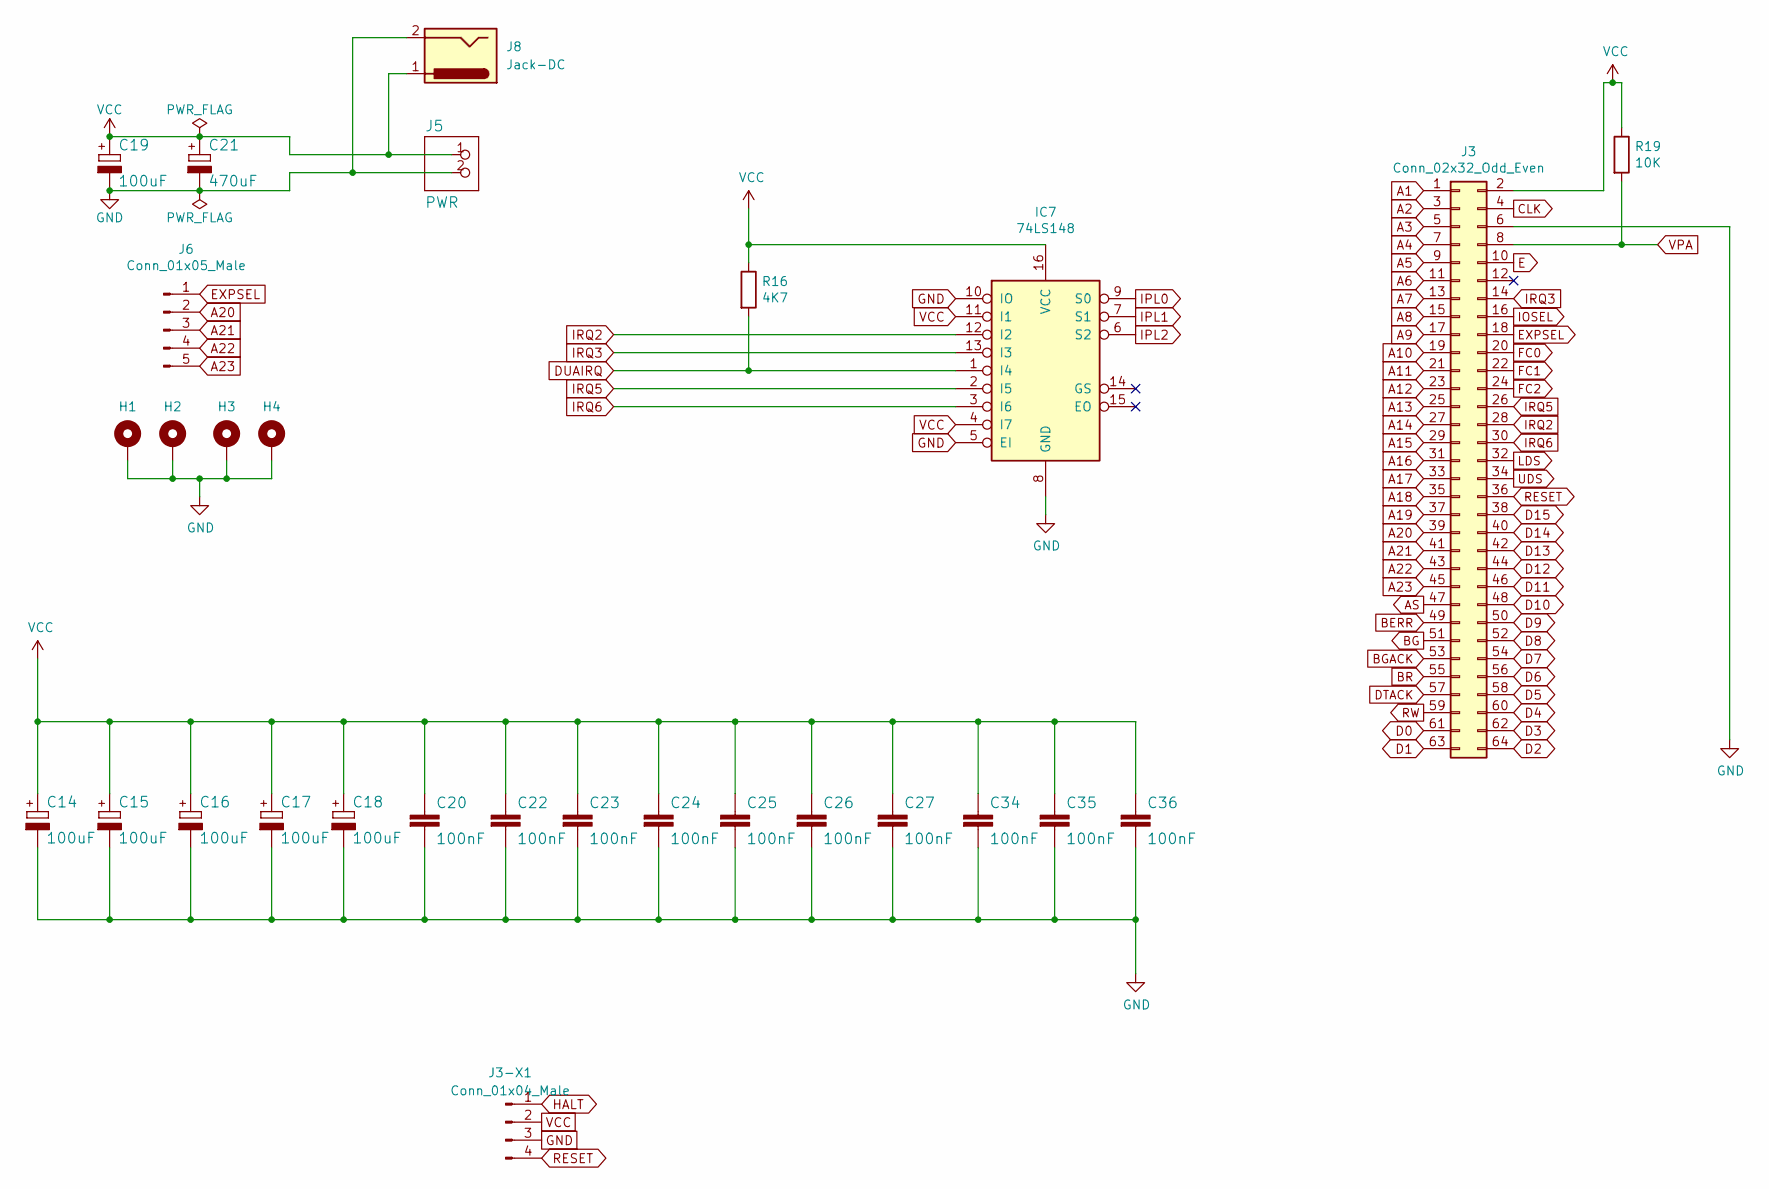
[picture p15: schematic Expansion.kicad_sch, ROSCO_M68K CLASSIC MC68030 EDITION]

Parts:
C14, C15, C16, C17, C18, C19: 100uF; E2,5-5
C20, C22, C23, C24, C25, C26, C27, C34, C35, C36: 100nF; C2.5-3
C21: 470uF; E3,5-10
H1, H2, H3, H4: MountingHole; MountingHole_3.2mm_M3_Pad
IC7: 74LS148; DIP-16_W7.62mm_LongPads
J3: Conn_02x32_Odd_Even; PinHeader_2x32_P2.54mm_Vertical
J3-X1: Conn_01x04_Male; PinHeader_1x04_P2.54mm_Vertical
J5: PWR; 1X02
J6: Conn_01x05_Male; PinHeader_1x05_P2.54mm_Vertical
J8: Jack-DC; BarrelJack_Horizontal
R16: 4K7; 0207_10
R19: 10K; 0207_10

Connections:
A1: J3.1; also elsewhere on the board
A2: J3.3; also elsewhere on the board
A3: J3.5; also elsewhere on the board
A4: J3.7; also elsewhere on the board
A5: J3.9; also elsewhere on the board
A6: J3.11; also elsewhere on the board
A7: J3.13; also elsewhere on the board
A8: J3.15; also elsewhere on the board
A9: J3.17; also elsewhere on the board
A10: J3.19; also elsewhere on the board
A11: J3.21; also elsewhere on the board
A12: J3.23; also elsewhere on the board
A13: J3.25; also elsewhere on the board
A14: J3.27; also elsewhere on the board
A15: J3.29; also elsewhere on the board
A16: J3.31; also elsewhere on the board
A17: J3.33; also elsewhere on the board
A18: J3.35; also elsewhere on the board
A19: J3.37; also elsewhere on the board
A20: J3.39, J6.2; also elsewhere on the board
A21: J3.41, J6.3; also elsewhere on the board
A22: J3.43, J6.4; also elsewhere on the board
A23: J3.45, J6.5; also elsewhere on the board
AS: J3.47; also elsewhere on the board
BERR: J3.49; also elsewhere on the board
BG: J3.51; also elsewhere on the board
BGACK: J3.53; also elsewhere on the board
BR: J3.55; also elsewhere on the board
CLK: J3.4; also elsewhere on the board
D0: J3.61; also elsewhere on the board
D1: J3.63; also elsewhere on the board
D2: J3.64; also elsewhere on the board
D3: J3.62; also elsewhere on the board
D4: J3.60; also elsewhere on the board
D5: J3.58; also elsewhere on the board
D6: J3.56; also elsewhere on the board
D7: J3.54; also elsewhere on the board
D8: J3.52; also elsewhere on the board
D9: J3.50; also elsewhere on the board
D10: J3.48; also elsewhere on the board
D11: J3.46; also elsewhere on the board
D12: J3.44; also elsewhere on the board
D13: J3.42; also elsewhere on the board
D14: J3.40; also elsewhere on the board
D15: J3.38; also elsewhere on the board
DTACK: J3.57; also elsewhere on the board
DUAIRQ: IC7.1 (I4), R16.2; also elsewhere on the board
E: J3.10; also elsewhere on the board
EXPSEL: J3.18, J6.1; also elsewhere on the board
FC0: J3.20; also elsewhere on the board
FC1: J3.22; also elsewhere on the board
FC2: J3.24; also elsewhere on the board
GND: C14.-, C15.-, C16.-, C17.-, C18.-, C19.-, C20.2, C21.-, C22.2, C23.2, C24.2, C25.2, C26.2, C27.2, C34.2, C35.2, C36.2, H1.1, H2.1, H3.1, H4.1, IC7.5 (EI), IC7.8 (GND), IC7.10 (IO), J3.6, J3-X1.3, J5.2, J8.2; also elsewhere on the board
HALT: J3-X1.1; also elsewhere on the board
IOSEL: J3.16; also elsewhere on the board
IPL0: IC7.9 (S0); also elsewhere on the board
IPL1: IC7.7 (S1); also elsewhere on the board
IPL2: IC7.6 (S2); also elsewhere on the board
IRQ2: IC7.12 (I2), J3.28; also elsewhere on the board
IRQ3: IC7.13 (I3), J3.14; also elsewhere on the board
IRQ5: IC7.2 (I5), J3.26; also elsewhere on the board
IRQ6: IC7.3 (I6), J3.30; also elsewhere on the board
LDS: J3.32; also elsewhere on the board
RESET: J3.36, J3-X1.4; also elsewhere on the board
RW: J3.59; also elsewhere on the board
UDS: J3.34; also elsewhere on the board
VCC: C14.+, C15.+, C16.+, C17.+, C18.+, C19.+, C20.1, C21.+, C22.1, C23.1, C24.1, C25.1, C26.1, C27.1, C34.1, C35.1, C36.1, IC7.4 (I7), IC7.11 (I1), IC7.16 (VCC), J3.2, J3-X1.2, J5.1, J8.1, R16.1, R19.1; also elsewhere on the board
VPA: J3.8, R19.2; also elsewhere on the board

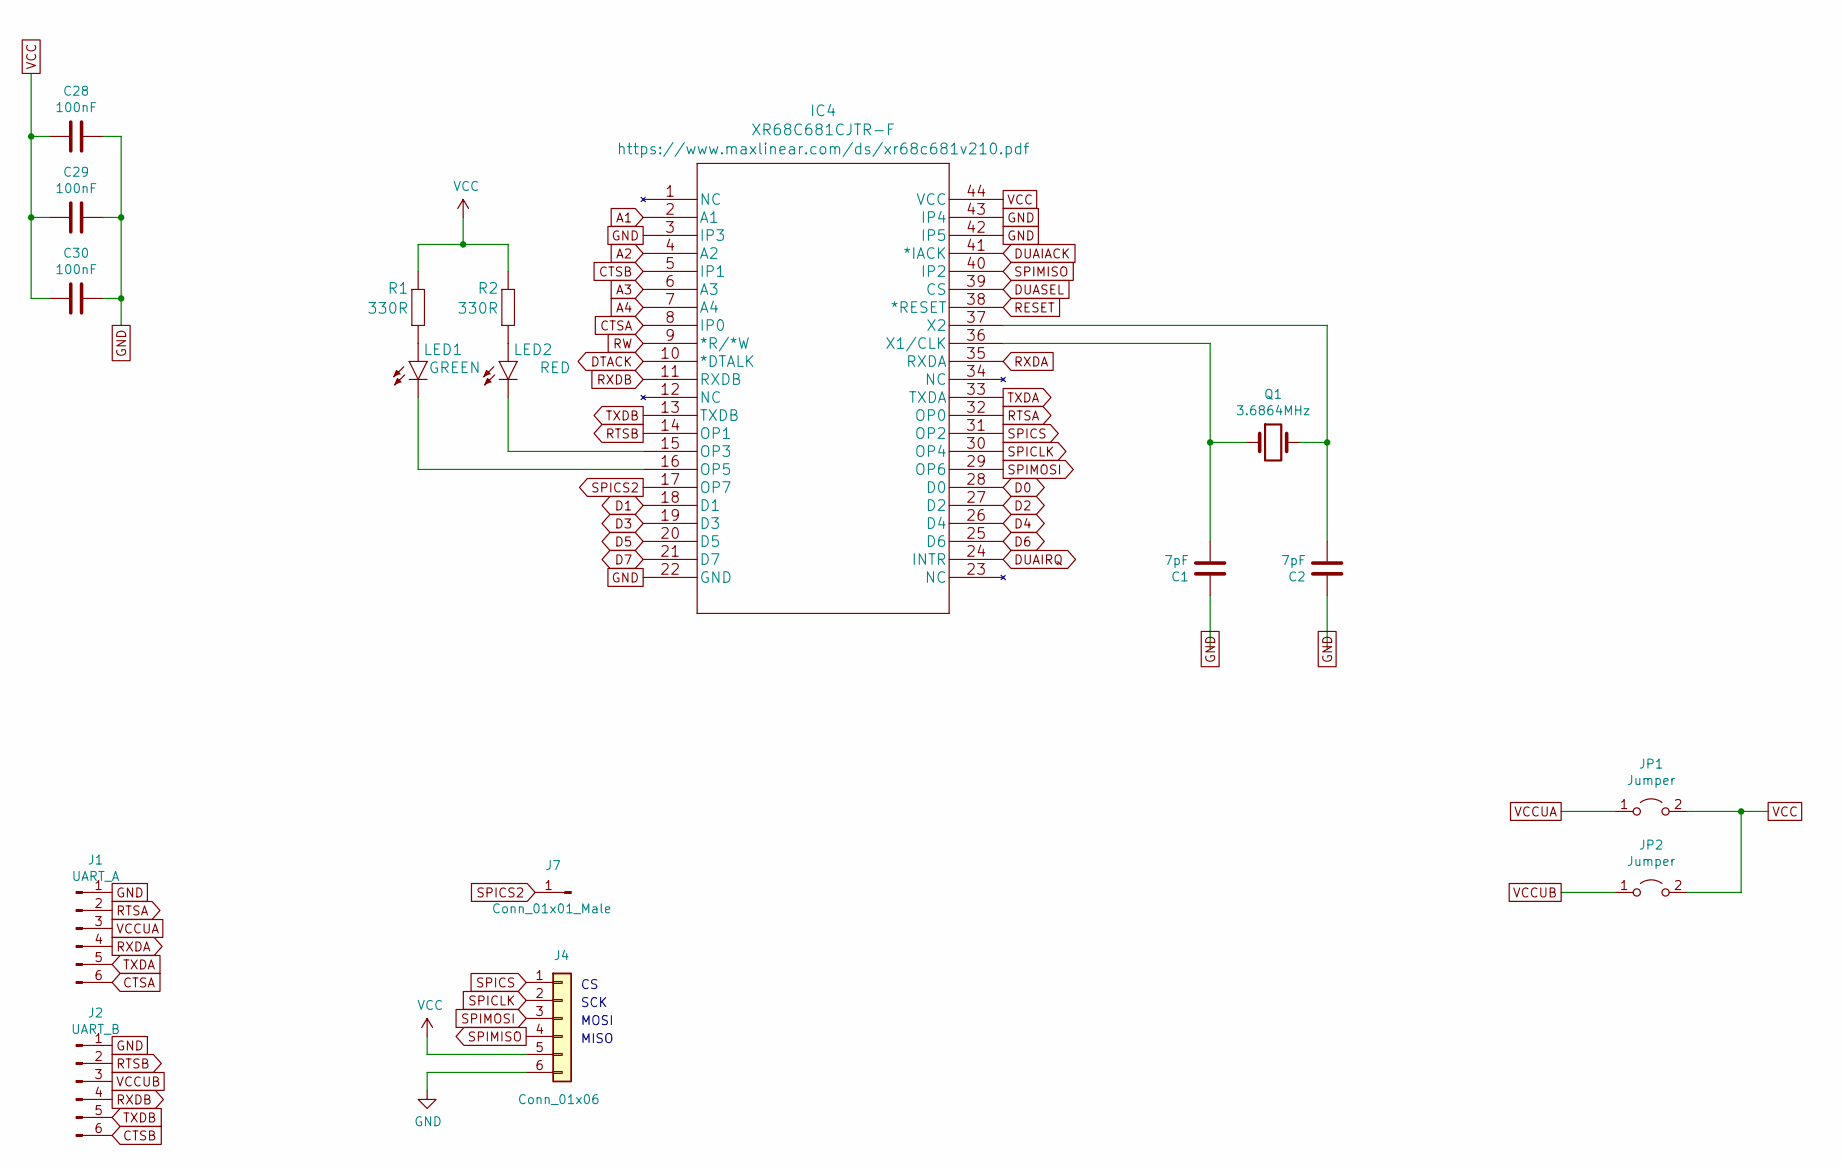
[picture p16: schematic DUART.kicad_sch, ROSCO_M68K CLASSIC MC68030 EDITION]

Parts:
C1, C2: 7pF; C2.5_or_3.5-3
C28, C29, C30: 100nF; C2.5-3
IC4: XR68C681CJTR-F; PLCC-44_THT-Socket
J1: UART_A; 1X06
J2: UART_B; 1X06
J4: Conn_01x06; 1X06
J7: Conn_01x01_Male; PinHeader_1x01_P2.54mm_Vertical
JP1, JP2: Jumper; 1X02
LED1: GREEN; LED5MM
LED2: RED; LED5MM
Q1: 3.6864MHz; Crystal_HC49-4H_Vertical
R1, R2: 330R; 0207_10

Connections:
A1: IC4.2 (A1); also elsewhere on the board
A2: IC4.4 (A2); also elsewhere on the board
A3: IC4.6 (A3); also elsewhere on the board
A4: IC4.7 (A4); also elsewhere on the board
CTSA: IC4.8 (IP0), J1.6
CTSB: IC4.5 (IP1), J2.6
D0: IC4.28 (D0); also elsewhere on the board
D1: IC4.18 (D1); also elsewhere on the board
D2: IC4.27 (D2); also elsewhere on the board
D3: IC4.19 (D3); also elsewhere on the board
D4: IC4.26 (D4); also elsewhere on the board
D5: IC4.20 (D5); also elsewhere on the board
D6: IC4.25 (D6); also elsewhere on the board
D7: IC4.21 (D7); also elsewhere on the board
DTACK: IC4.10 (*DTALK); also elsewhere on the board
DUAIACK: IC4.41 (*IACK); also elsewhere on the board
DUAIRQ: IC4.24 (INTR); also elsewhere on the board
DUASEL: IC4.39 (CS); also elsewhere on the board
GND: C1.1, C2.1, C28.1, C29.1, C30.1, IC4.3 (IP3), IC4.22 (GND), IC4.42 (IP5), IC4.43 (IP4), J1.1, J2.1, J4.6; also elsewhere on the board
unnamed: IC4.15 (OP3), LED2.K (C)
unnamed: IC4.16 (OP5), LED1.K (C)
unnamed: C1.2, IC4.36 (X1/CLK), Q1.1
unnamed: C2.2, IC4.37 (X2), Q1.2
unnamed: LED1.A, R1.1
unnamed: LED2.A, R2.1
RESET: IC4.38 (*RESET); also elsewhere on the board
RTSA: IC4.32 (OP0), J1.2
RTSB: IC4.14 (OP1), J2.2
RW: IC4.9 (*R/*W); also elsewhere on the board
RXDA: IC4.35 (RXDA), J1.4
RXDB: IC4.11 (RXDB), J2.4
SPICLK: IC4.30 (OP4), J4.2
SPICS: IC4.31 (OP2), J4.1
SPICS2: IC4.17 (OP7), J7.1
SPIMISO: IC4.40 (IP2), J4.4
SPIMOSI: IC4.29 (OP6), J4.3
TXDA: IC4.33 (TXDA), J1.5
TXDB: IC4.13 (TXDB), J2.5
VCC: C28.2, C29.2, C30.2, IC4.44 (VCC), J4.5, JP1.2 (B), JP2.2 (B), R1.2, R2.2; also elsewhere on the board
VCCUA: J1.3, JP1.1 (A)
VCCUB: J2.3, JP2.1 (A)

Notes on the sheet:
MISO
SCK
MOSI

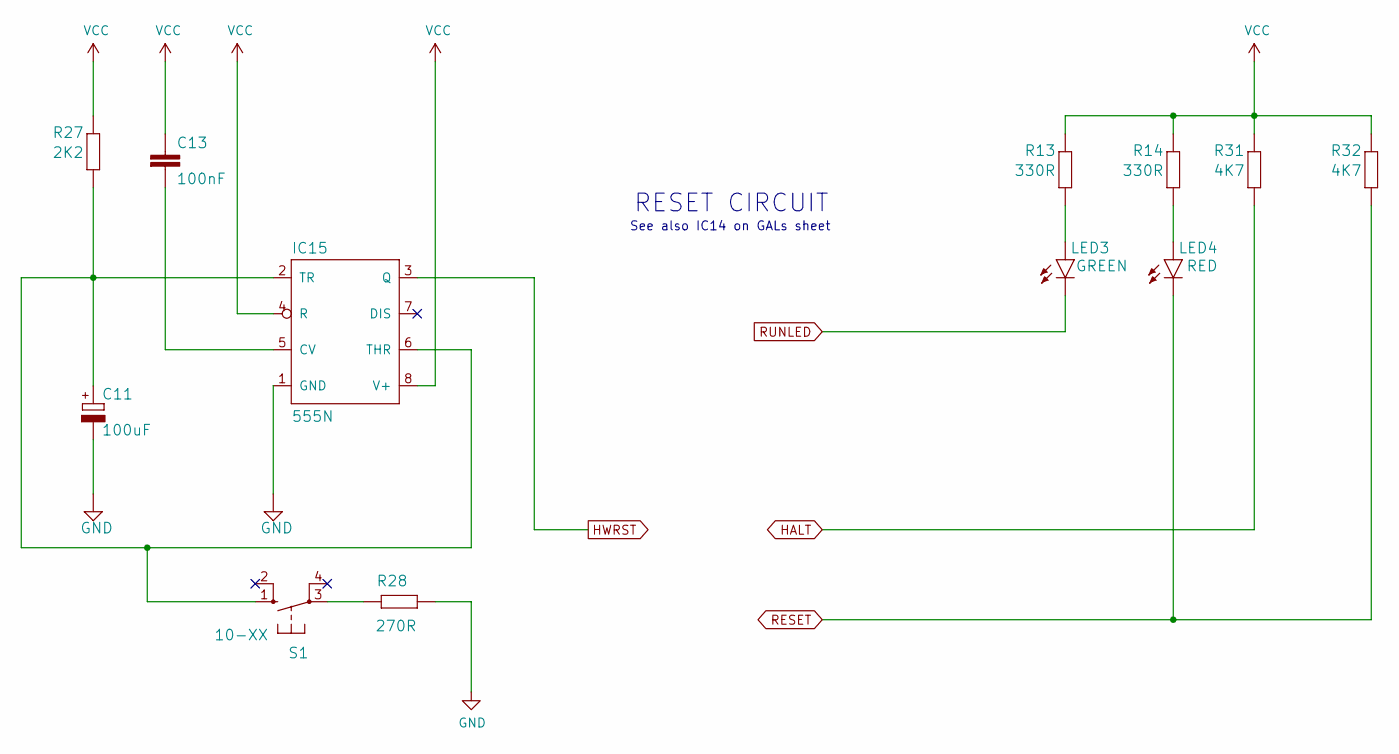
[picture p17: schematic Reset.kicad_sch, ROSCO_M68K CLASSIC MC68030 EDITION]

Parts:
C11: 100uF; E2,5-5
C13: 100nF; C2.5-3
IC15: 555N; DIP-8_W7.62mm_LongPads
LED3: GREEN; LED5MM
LED4: RED; LED5MM
R13, R14: 330R; 0207_10
R27: 2K2; 0207_10
R28: 270R; 0207_10
R31, R32: 4K7; 0207_10
S1: 10-XX; B3F-10XX

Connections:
GND: C11.-, IC15.1 (GND), R28.1; also elsewhere on the board
HALT: R31.1; also elsewhere on the board
HWRST: IC15.3 (Q); also elsewhere on the board
unnamed: C13.2, IC15.5 (CV)
unnamed: C11.+, IC15.2 (TR), IC15.6 (THR), R27.1, S1.1 (S)
unnamed: LED3.A, R13.1
unnamed: LED4.A, R14.1
unnamed: R28.2, S1.3
RESET: LED4.K (C), R32.1; also elsewhere on the board
RUNLED: LED3.K (C); also elsewhere on the board
VCC: C13.1, IC15.4 (R), IC15.8 (V+), R13.2, R14.2, R27.2, R31.2, R32.2; also elsewhere on the board

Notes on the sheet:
See also IC14 on GALs sheet
RESET CIRCUIT

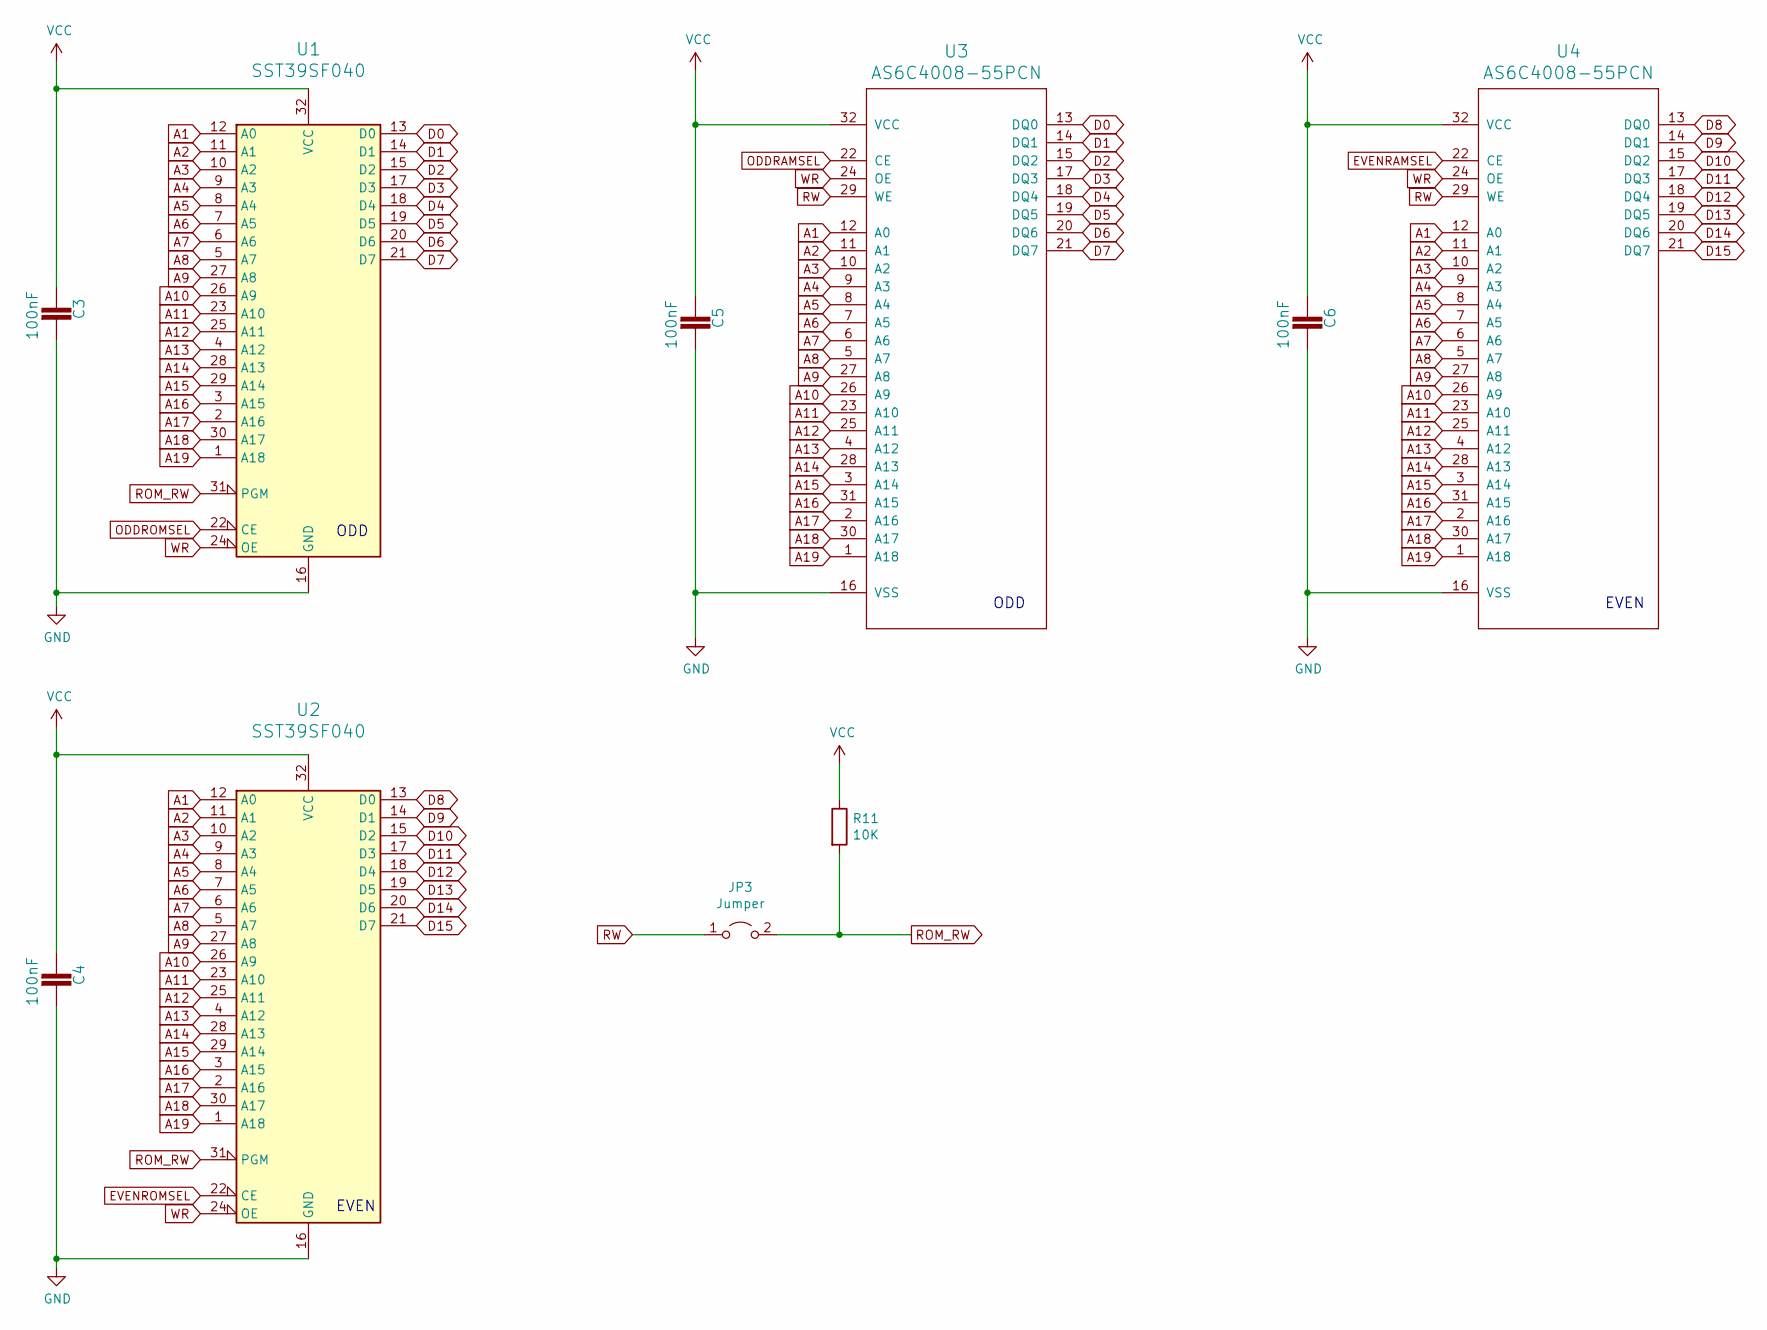
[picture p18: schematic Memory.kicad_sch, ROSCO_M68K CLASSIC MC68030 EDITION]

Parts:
C3, C4, C5, C6: 100nF; C2.5-3
JP3: Jumper; 1X02
R11: 10K; 0207_10
U1, U2: SST39SF040; DIP-32_W15.24mm_Socket_LongPads
U3, U4: AS6C4008-55PCN; DIP-32_W15.24mm_Socket_LongPads

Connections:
A1: U1.12 (A0), U2.12 (A0), U3.12 (A0), U4.12 (A0); also elsewhere on the board
A2: U1.11 (A1), U2.11 (A1), U3.11 (A1), U4.11 (A1); also elsewhere on the board
A3: U1.10 (A2), U2.10 (A2), U3.10 (A2), U4.10 (A2); also elsewhere on the board
A4: U1.9 (A3), U2.9 (A3), U3.9 (A3), U4.9 (A3); also elsewhere on the board
A5: U1.8 (A4), U2.8 (A4), U3.8 (A4), U4.8 (A4); also elsewhere on the board
A6: U1.7 (A5), U2.7 (A5), U3.7 (A5), U4.7 (A5); also elsewhere on the board
A7: U1.6 (A6), U2.6 (A6), U3.6 (A6), U4.6 (A6); also elsewhere on the board
A8: U1.5 (A7), U2.5 (A7), U3.5 (A7), U4.5 (A7); also elsewhere on the board
A9: U1.27 (A8), U2.27 (A8), U3.27 (A8), U4.27 (A8); also elsewhere on the board
A10: U1.26 (A9), U2.26 (A9), U3.26 (A9), U4.26 (A9); also elsewhere on the board
A11: U1.23 (A10), U2.23 (A10), U3.23 (A10), U4.23 (A10); also elsewhere on the board
A12: U1.25 (A11), U2.25 (A11), U3.25 (A11), U4.25 (A11); also elsewhere on the board
A13: U1.4 (A12), U2.4 (A12), U3.4 (A12), U4.4 (A12); also elsewhere on the board
A14: U1.28 (A13), U2.28 (A13), U3.28 (A13), U4.28 (A13); also elsewhere on the board
A15: U1.29 (A14), U2.29 (A14), U3.3 (A14), U4.3 (A14); also elsewhere on the board
A16: U1.3 (A15), U2.3 (A15), U3.31 (A15), U4.31 (A15); also elsewhere on the board
A17: U1.2 (A16), U2.2 (A16), U3.2 (A16), U4.2 (A16); also elsewhere on the board
A18: U1.30 (A17), U2.30 (A17), U3.30 (A17), U4.30 (A17); also elsewhere on the board
A19: U1.1 (A18), U2.1 (A18), U3.1 (A18), U4.1 (A18); also elsewhere on the board
D0: U1.13 (D0), U3.13 (DQ0); also elsewhere on the board
D1: U1.14 (D1), U3.14 (DQ1); also elsewhere on the board
D2: U1.15 (D2), U3.15 (DQ2); also elsewhere on the board
D3: U1.17 (D3), U3.17 (DQ3); also elsewhere on the board
D4: U1.18 (D4), U3.18 (DQ4); also elsewhere on the board
D5: U1.19 (D5), U3.19 (DQ5); also elsewhere on the board
D6: U1.20 (D6), U3.20 (DQ6); also elsewhere on the board
D7: U1.21 (D7), U3.21 (DQ7); also elsewhere on the board
D8: U2.13 (D0), U4.13 (DQ0); also elsewhere on the board
D9: U2.14 (D1), U4.14 (DQ1); also elsewhere on the board
D10: U2.15 (D2), U4.15 (DQ2); also elsewhere on the board
D11: U2.17 (D3), U4.17 (DQ3); also elsewhere on the board
D12: U2.18 (D4), U4.18 (DQ4); also elsewhere on the board
D13: U2.19 (D5), U4.19 (DQ5); also elsewhere on the board
D14: U2.20 (D6), U4.20 (DQ6); also elsewhere on the board
D15: U2.21 (D7), U4.21 (DQ7); also elsewhere on the board
EVENRAMSEL: U4.22 (CE); also elsewhere on the board
EVENROMSEL: U2.22 (CE); also elsewhere on the board
GND: C3.2, C4.2, C5.2, C6.2, U1.16 (GND), U2.16 (GND), U3.16 (VSS), U4.16 (VSS); also elsewhere on the board
ODDRAMSEL: U3.22 (CE); also elsewhere on the board
ODDROMSEL: U1.22 (CE); also elsewhere on the board
ROM_RW: JP3.2 (B), R11.2, U1.31 (PGM), U2.31 (PGM)
RW: JP3.1 (A), U3.29 (WE), U4.29 (WE); also elsewhere on the board
VCC: C3.1, C4.1, C5.1, C6.1, R11.1, U1.32 (VCC), U2.32 (VCC), U3.32 (VCC), U4.32 (VCC); also elsewhere on the board
WR: U1.24 (OE), U2.24 (OE), U3.24 (OE), U4.24 (OE); also elsewhere on the board

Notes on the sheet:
EVEN
ODD

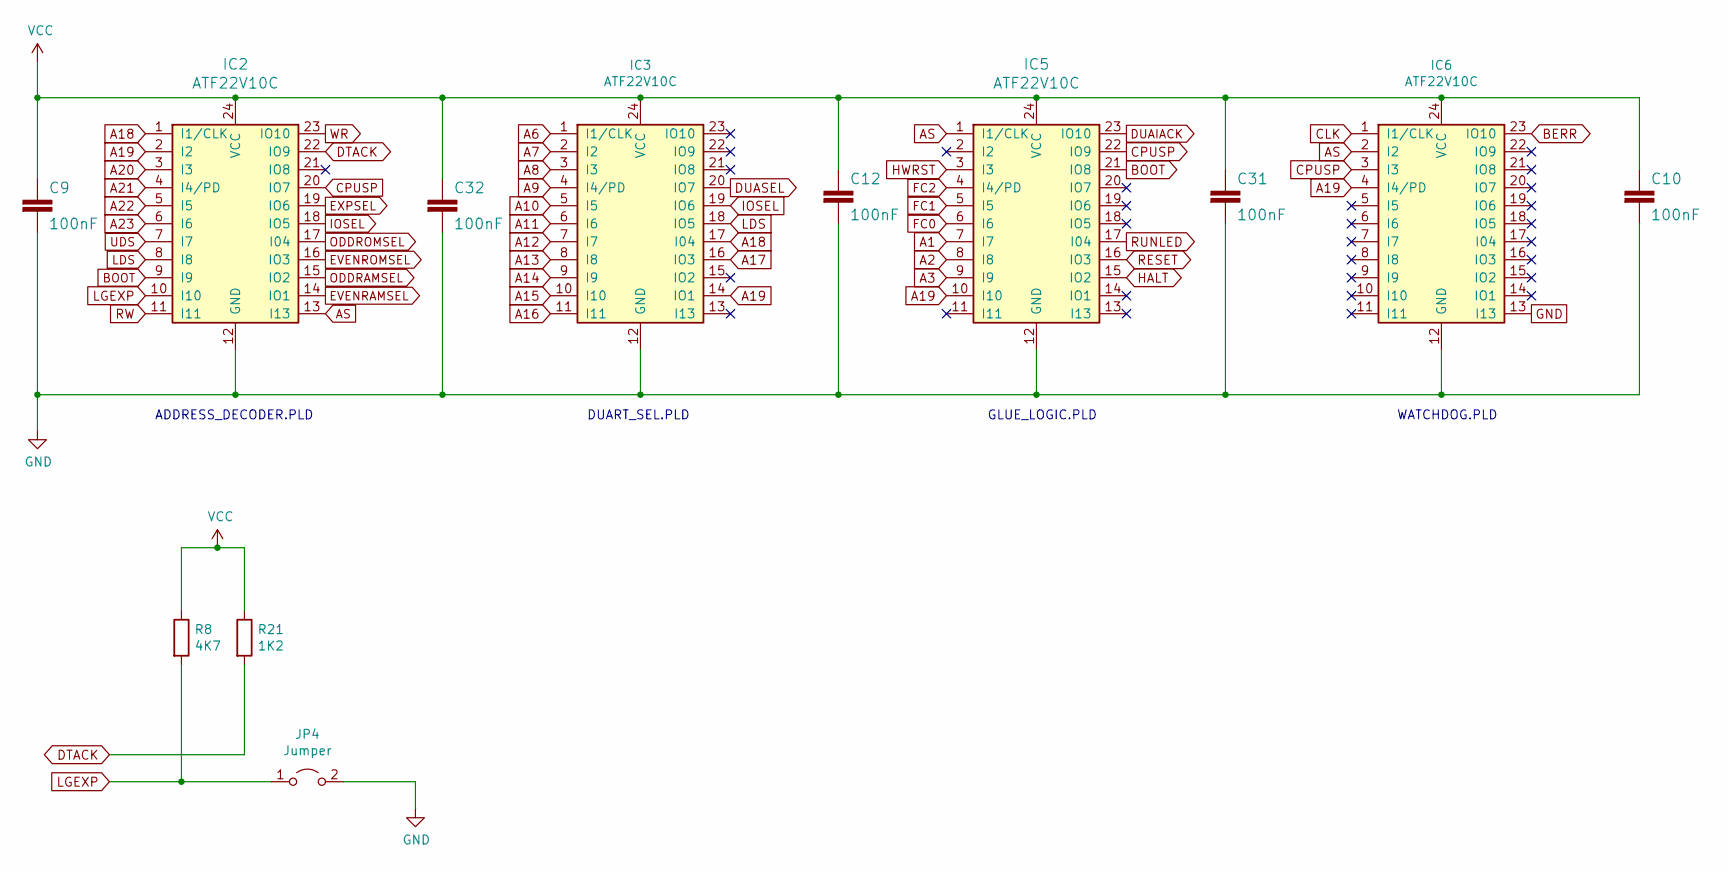
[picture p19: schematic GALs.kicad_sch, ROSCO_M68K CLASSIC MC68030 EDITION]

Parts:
C9, C10, C12, C31, C32: 100nF; C2.5-3
IC2, IC3, IC5, IC6: ATF22V10C; DIP-24_W7.62mm_Socket_LongPads
JP4: Jumper; 1X02
R8: 4K7; 0207_10
R21: 1K2; 0207_10

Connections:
A1: IC5.7 (I7); also elsewhere on the board
A2: IC5.8 (I8); also elsewhere on the board
A3: IC5.9 (I9); also elsewhere on the board
A6: IC3.1 (I1/CLK); also elsewhere on the board
A7: IC3.2 (I2); also elsewhere on the board
A8: IC3.3 (I3); also elsewhere on the board
A9: IC3.4 (I4/PD); also elsewhere on the board
A10: IC3.5 (I5); also elsewhere on the board
A11: IC3.6 (I6); also elsewhere on the board
A12: IC3.7 (I7); also elsewhere on the board
A13: IC3.8 (I8); also elsewhere on the board
A14: IC3.9 (I9); also elsewhere on the board
A15: IC3.10 (I10); also elsewhere on the board
A16: IC3.11 (I11); also elsewhere on the board
A17: IC3.16 (IO3); also elsewhere on the board
A18: IC2.1 (I1/CLK), IC3.17 (I04); also elsewhere on the board
A19: IC2.2 (I2), IC3.14 (IO1), IC5.10 (I10), IC6.4 (I4/PD); also elsewhere on the board
A20: IC2.3 (I3); also elsewhere on the board
A21: IC2.4 (I4/PD); also elsewhere on the board
A22: IC2.5 (I5); also elsewhere on the board
A23: IC2.6 (I6); also elsewhere on the board
AS: IC2.13 (I13), IC5.1 (I1/CLK), IC6.2 (I2); also elsewhere on the board
BERR: IC6.23 (IO10); also elsewhere on the board
BOOT: IC2.9 (I9), IC5.21 (IO8)
CLK: IC6.1 (I1/CLK); also elsewhere on the board
CPUSP: IC2.20 (IO7), IC5.22 (IO9), IC6.3 (I3)
DTACK: IC2.22 (IO9), R21.2; also elsewhere on the board
DUAIACK: IC5.23 (IO10); also elsewhere on the board
DUASEL: IC3.20 (IO7); also elsewhere on the board
EVENRAMSEL: IC2.14 (IO1); also elsewhere on the board
EVENROMSEL: IC2.16 (IO3); also elsewhere on the board
EXPSEL: IC2.19 (IO6); also elsewhere on the board
FC0: IC5.6 (I6); also elsewhere on the board
FC1: IC5.5 (I5); also elsewhere on the board
FC2: IC5.4 (I4/PD); also elsewhere on the board
GND: C9.2, C10.2, C12.2, C31.2, C32.2, IC2.12 (GND), IC3.12 (GND), IC5.12 (GND), IC6.12 (GND), IC6.13 (I13), JP4.2 (B); also elsewhere on the board
HALT: IC5.15 (IO2); also elsewhere on the board
HWRST: IC5.3 (I3); also elsewhere on the board
IOSEL: IC2.18 (IO5), IC3.19 (IO6); also elsewhere on the board
LDS: IC2.8 (I8), IC3.18 (IO5); also elsewhere on the board
LGEXP: IC2.10 (I10), JP4.1 (A), R8.2
ODDRAMSEL: IC2.15 (IO2); also elsewhere on the board
ODDROMSEL: IC2.17 (I04); also elsewhere on the board
RESET: IC5.16 (IO3); also elsewhere on the board
RUNLED: IC5.17 (I04); also elsewhere on the board
RW: IC2.11 (I11); also elsewhere on the board
UDS: IC2.7 (I7); also elsewhere on the board
VCC: C9.1, C10.1, C12.1, C31.1, C32.1, IC2.24 (VCC), IC3.24 (VCC), IC5.24 (VCC), IC6.24 (VCC), R8.1, R21.1; also elsewhere on the board
WR: IC2.23 (IO10); also elsewhere on the board

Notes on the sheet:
GLUE_LOGIC.PLD
ADDRESS_DECODER.PLD
DUART_SEL.PLD
WATCHDOG.PLD

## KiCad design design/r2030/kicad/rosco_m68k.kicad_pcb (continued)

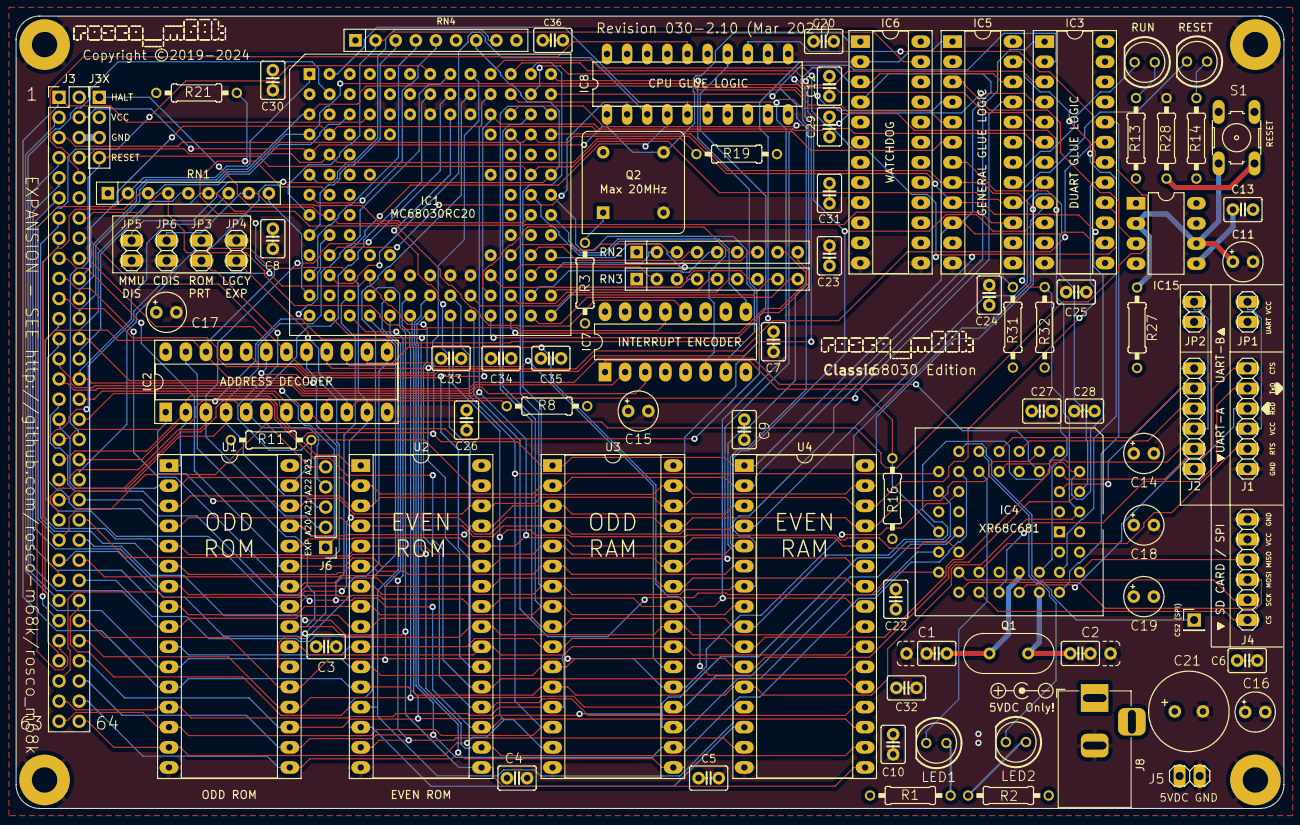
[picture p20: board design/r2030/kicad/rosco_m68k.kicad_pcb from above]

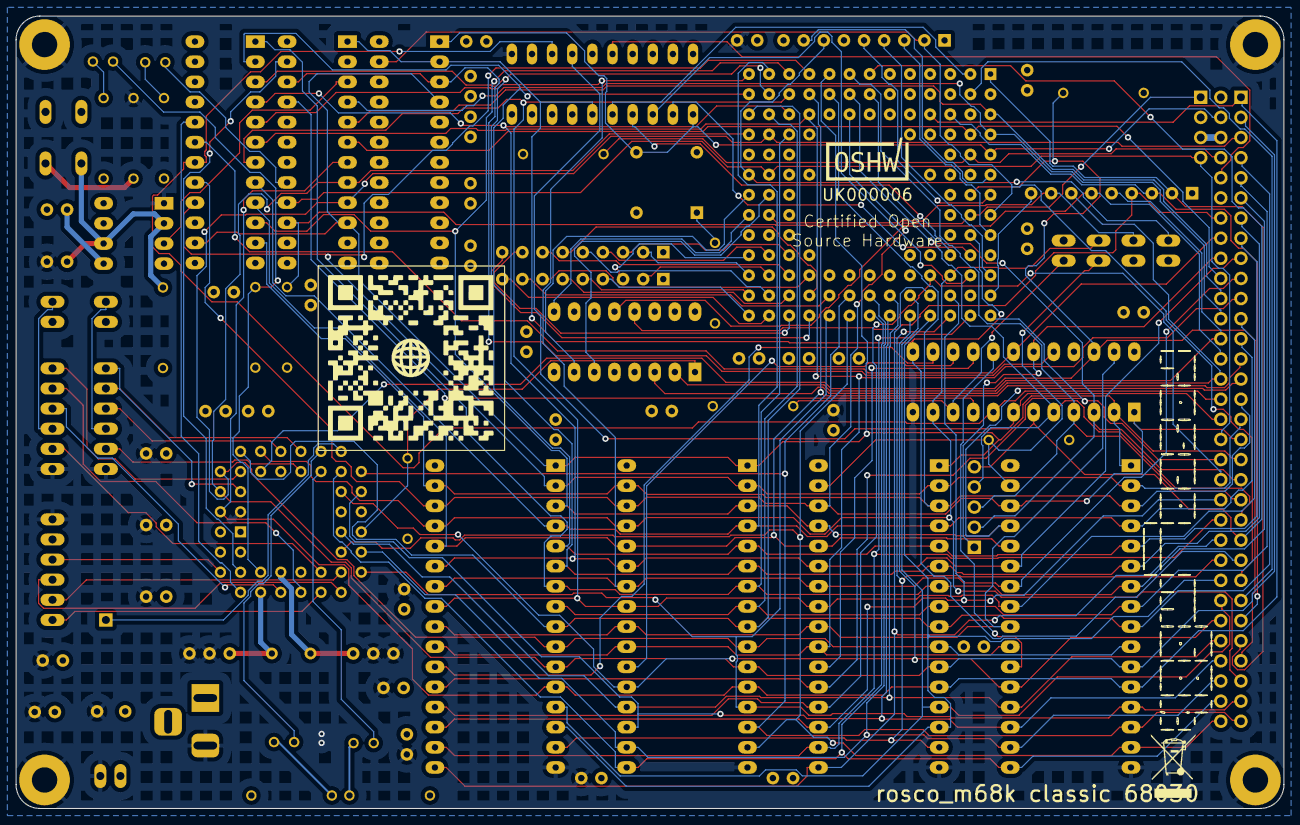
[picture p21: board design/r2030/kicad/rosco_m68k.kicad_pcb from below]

Board: 4 copper layers, 160.0 x 100.0 mm, 97 parts (2 on the bottom side), 135 nets.

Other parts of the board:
OSHW_Mono_0.25_Scale: UK000006; OSHW_Mono_0.25_Scale
rosco_m68k, rosco_m68k_mid: SM-rosco_m68k_logo
weee: WEEE-Logo_5.6x8mm_SilkScreen

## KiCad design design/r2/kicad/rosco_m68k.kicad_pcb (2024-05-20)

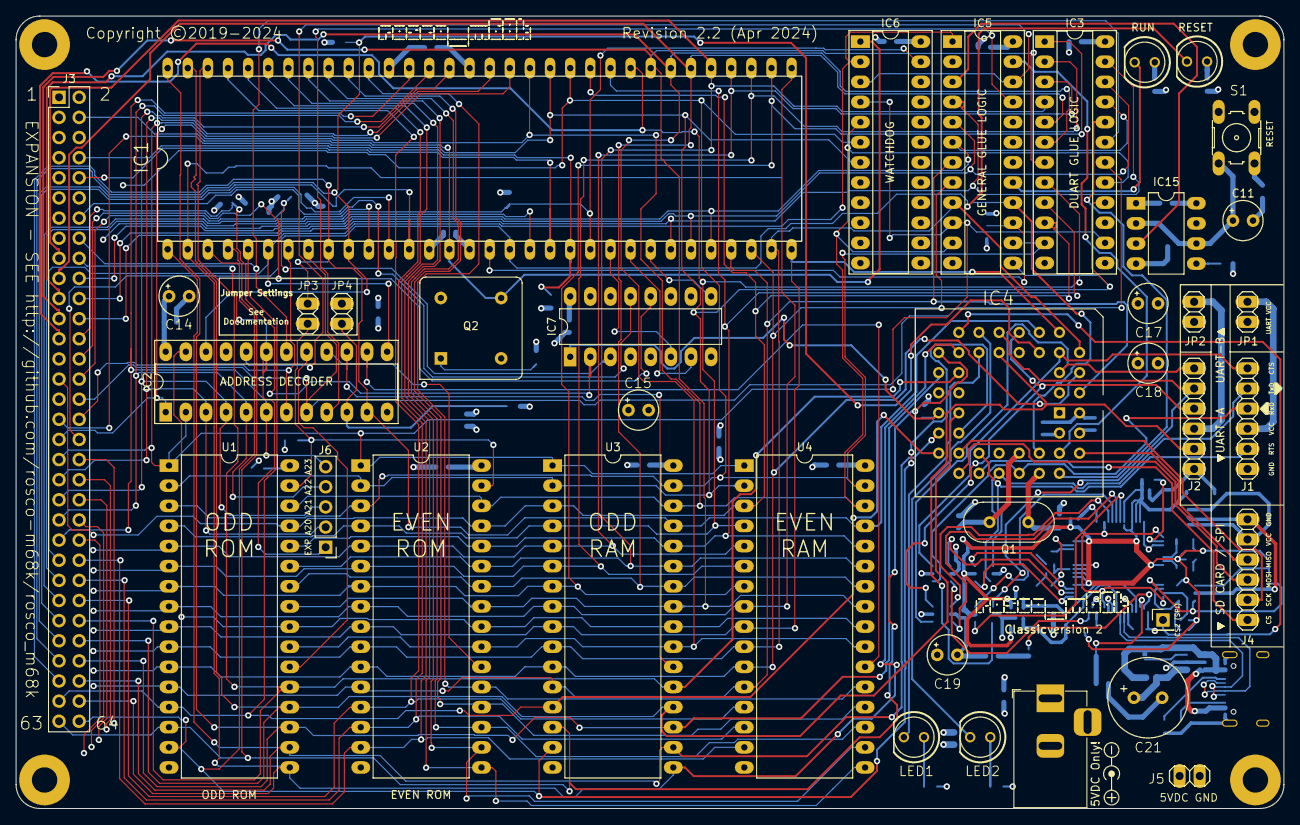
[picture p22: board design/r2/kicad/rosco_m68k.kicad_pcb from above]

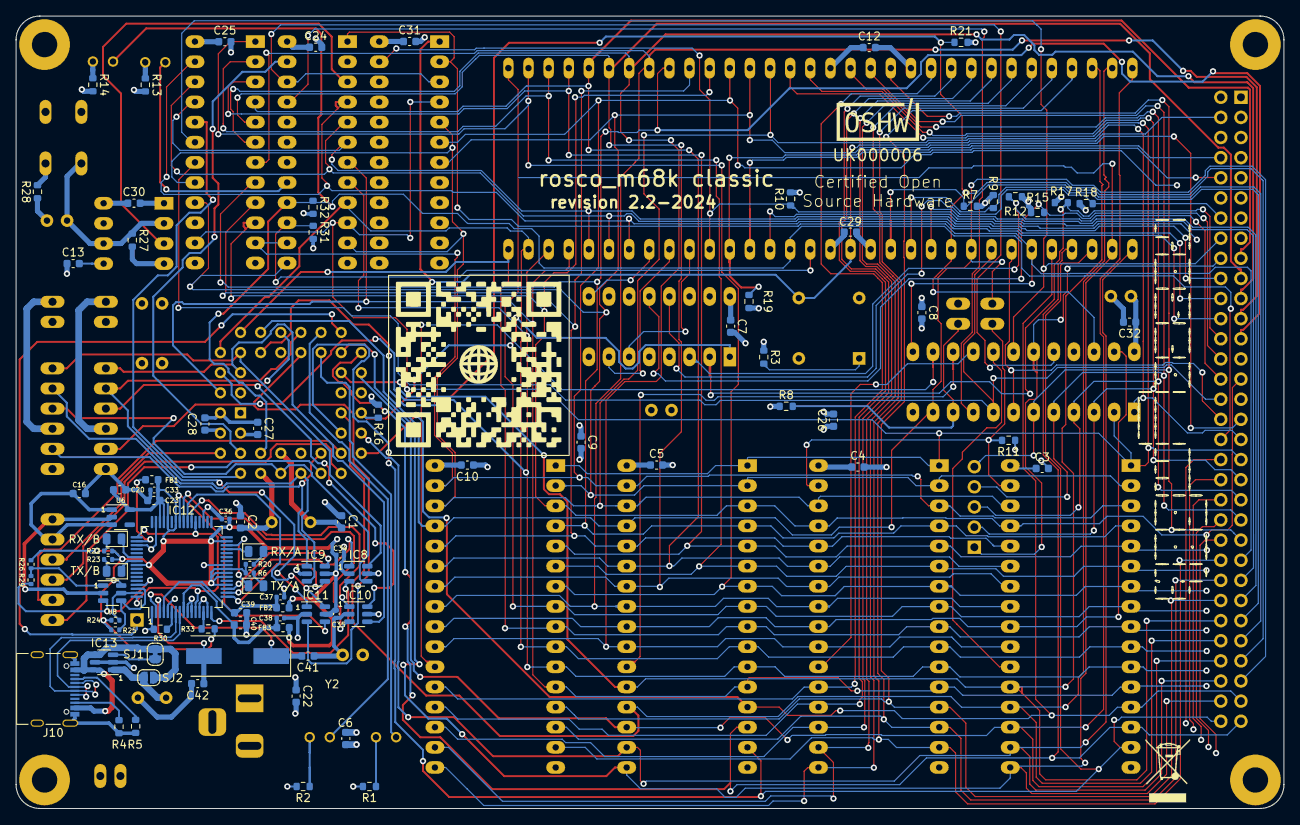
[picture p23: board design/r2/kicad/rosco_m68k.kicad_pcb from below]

Board: 4 copper layers, 160.0 x 100.0 mm, 134 parts (90 on the bottom side), 144 nets.

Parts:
BIGROSCO: MD-rosco_m68k_logo
C1, C2: 7pF; C_0603_1608Metric
C3, C4, C5, C6, C7, C8, C9, C10, C12, C13, C22, C24, C25, C26, C27, C28, C29, C30, C31, C32: 100nF; C_0603_1608Metric
C11, C14, C15, C17, C18, C19: 100uF; E2,5-5
C16, C20, C23, C39, C40: 4.7uF; C_0603_1608Metric
C21: 470uF; E3,5-10
C33, C34, C35, C36, C37, C38: 100nF; C_0402_1005Metric
C41, C42: 27pF; C_0603_1608Metric
FB1, FB2, FB3: BLM18HE152SN1D; L_0603_1608Metric
H1, H2, H3, H4: MountingHole; MountingHole_3.2mm_M3_Pad
IC1: MC68010P10; DIL64
IC2, IC3, IC5, IC6: ATF22V10C; DIP-24_W7.62mm_Socket_LongPads
IC4: XR68C681CJTR-F; PLCC-44_THT-Socket
IC7: 74LS148; DIP-16_W7.62mm_LongPads
IC8, IC9, IC10, IC11: SN74LVC2G17; SOT-23-6
IC12: FT2232HL; LQFP-64_10x10mm_P0.5mm
IC13: TPS22929D; SOT-23-6
IC15: 555N; DIP-8_W7.62mm_LongPads
J1: UART_A; 1X06
J2: UART_B; 1X06
J3: Conn_02x32_Odd_Even; PinHeader_2x32_P2.54mm_Vertical
J4: Conn_01x06; 1X06
J5: PWR; 1X02
J6: Conn_01x05_Male; PinHeader_1x05_P2.54mm_Vertical
J7: Conn_01x01_Male; PinHeader_1x01_P2.54mm_Vertical
J9: Jack-DC; BarrelJack_Horizontal
J10: USB_C_Receptacle_PowerOnly_6P; USB_C_Receptacle_Palconn_UTC16-G
JP1, JP2, JP3, JP4: Jumper; 1X02
LED1, LED3: GREEN; LED5MM
LED2, LED4: RED; LED5MM
LED5, LED6, LED7, LED8: RED; LED_0805_2012Metric
OSHW_Mono_0.25_Scale: UK000006; OSHW_Mono_0.25_Scale
POLARITY: Symbol_Barrel_Polarity
Q1: 3.6864MHz; Crystal_HC49-4H_Vertical
Q2: 5H8ET-10.000; Oscillator_DIP-8
R1, R2, R13, R14, R33: 1K; R_0603_1608Metric
R3, R7, R8, R9, R10, R12, R15, R16, R17, R18, R31, R32: 4K7; R_0603_1608Metric
R4, R5: 5.1K; R_0603_1608Metric
R6, R20, R22, R23: 2K; R_0402_1005Metric
R11, R19: 10K; R_0603_1608Metric
R21: 1K2; R_0603_1608Metric
R24, R25, R26: 10K; R_0402_1005Metric
R27: 2K2; R_0603_1608Metric
R28: 270R; R_0603_1608Metric
R29: 2.2K; R_0402_1005Metric
R30: 12K; R_0603_1608Metric
S1: 10-XX; B3F-10XX
SJ1: SHORT; SolderJumper-2_P1.3mm_Bridged_RoundedPad1.0x1.5mm
SJ2: OPEN; SolderJumper-2_P1.3mm_Open_RoundedPad1.0x1.5mm
U1, U2: SST39SF040; DIP-32_W15.24mm_LongPads
U3, U4: AS6C4008-55PCN; DIP-32_W15.24mm_LongPads
U6: AP2127K-3.3; SOT-23-5
U8: 93LC56BT-I/OT; SOT-23-6
WEEE: WEEE-Logo_5.6x8mm_SilkScreen
Y2: 12MHz; Crystal_SMD_HC49-SD
rosco: SM-rosco_m68k_logo

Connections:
+3V3: C20.1, C23.1, C33.1, C34.1, C35.1, C36.1, FB1.2, FB2.2, FB3.2, IC9.5 (VCC), IC11.5 (VCC), IC12.20 (VCCIO), IC12.22 (ADBUS5), IC12.23 (ADBUS6), IC12.24 (ADBUS7), IC12.31 (VCCIO), IC12.42 (VCCIO), IC12.44 (BDBUS5), IC12.45 (BDBUS6), IC12.46 (BDBUS7), IC12.56 (VCCIO), R6.2, R20.2, R22.2, R23.2, R24.1, R25.2, R26.2, R33.2, U6.5 (VOUT), U8.6 (VCC)
/FTDI (Optional)/EE_CLK: IC12.62 (EECLK), R25.1, U8.4 (CLK)
/FTDI (Optional)/EE_CS: IC12.63 (EECS), R24.2, U8.5 (CS)
/FTDI (Optional)/EE_DAT: IC12.61 (EEDATA), R29.1, U8.3 (DI)
/FTDI (Optional)/FTDI_CTSA: IC9.6 (Y1), IC12.19 (ADBUS3)
/FTDI (Optional)/FTDI_CTSB: IC11.4 (Y2), IC12.41 (BDBUS3)
/FTDI (Optional)/FTDI_RTSA: IC8.1 (IN_A), IC12.18 (ADBUS2)
/FTDI (Optional)/FTDI_RTSB: IC10.3 (IN_B), IC12.40 (BDBUS2)
/FTDI (Optional)/FTDI_RXA: IC9.4 (Y2), IC12.17 (ADBUS1)
/FTDI (Optional)/FTDI_RXB: IC11.6 (Y1), IC12.39 (BDBUS1)
/FTDI (Optional)/FTDI_TXA: IC8.3 (IN_B), IC12.16 (ADBUS0)
/FTDI (Optional)/FTDI_TXB: IC10.1 (IN_A), IC12.38 (BDBUS0)
/FTDI (Optional)/VCORE: IC12.12 (VCORE), IC12.37 (VCORE), IC12.49 (VREGOUT), IC12.64 (VCORE)
/FTDI (Optional)/VPHY: C37.1, C39.1, FB2.1, IC12.4 (VPHY)
/FTDI (Optional)/VPLL: C38.1, C40.1, FB3.1, IC12.9 (VPLL)
A1: IC1.29 (A1), IC4.2 (A1), IC5.7 (I7), J3.1, U1.12 (A0), U2.12 (A0), U3.12 (A0), U4.12 (A0)
A2: IC1.30 (A2), IC4.4 (A2), IC5.8 (I8), J3.3, U1.11 (A1), U2.11 (A1), U3.11 (A1), U4.11 (A1)
A3: IC1.31 (A3), IC4.6 (A3), IC5.9 (I9), J3.5, U1.10 (A2), U2.10 (A2), U3.10 (A2), U4.10 (A2)
A4: IC1.32 (A4), IC4.7 (A4), J3.7, U1.9 (A3), U2.9 (A3), U3.9 (A3), U4.9 (A3)
A5: IC1.33 (A5), J3.9, U1.8 (A4), U2.8 (A4), U3.8 (A4), U4.8 (A4)
A6: IC1.34 (A6), IC3.1 (I1/CLK), J3.11, U1.7 (A5), U2.7 (A5), U3.7 (A5), U4.7 (A5)
A7: IC1.35 (A7), IC3.2 (I2), J3.13, U1.6 (A6), U2.6 (A6), U3.6 (A6), U4.6 (A6)
A8: IC1.36 (A8), IC3.3 (I3), J3.15, U1.5 (A7), U2.5 (A7), U3.5 (A7), U4.5 (A7)
A9: IC1.37 (A9), IC3.4 (I4/PD), J3.17, U1.27 (A8), U2.27 (A8), U3.27 (A8), U4.27 (A8)
A10: IC1.38 (A10), IC3.5 (I5), J3.19, U1.26 (A9), U2.26 (A9), U3.26 (A9), U4.26 (A9)
A11: IC1.39 (A11), IC3.6 (I6), J3.21, U1.23 (A10), U2.23 (A10), U3.23 (A10), U4.23 (A10)
A12: IC1.40 (A12), IC3.7 (I7), J3.23, U1.25 (A11), U2.25 (A11), U3.25 (A11), U4.25 (A11)
A13: IC1.41 (A13), IC3.8 (I8), J3.25, U1.4 (A12), U2.4 (A12), U3.4 (A12), U4.4 (A12)
A14: IC1.42 (A14), IC3.9 (I9), J3.27, U1.28 (A13), U2.28 (A13), U3.28 (A13), U4.28 (A13)
A15: IC1.43 (A15), IC3.10 (I10), J3.29, U1.29 (A14), U2.29 (A14), U3.3 (A14), U4.3 (A14)
A16: IC1.44 (A16), IC3.11 (I11), IC5.14 (IO1), IC6.6 (I6), J3.31, U1.3 (A15), U2.3 (A15), U3.31 (A15), U4.31 (A15)
A17: IC1.45 (A17), IC3.16 (IO3), IC5.13 (I13), IC6.7 (I7), J3.33, U1.2 (A16), U2.2 (A16), U3.2 (A16), U4.2 (A16)
A18: IC1.46 (A18), IC2.1 (I1/CLK), IC3.17 (I04), IC5.11 (I11), IC6.5 (I5), J3.35, U1.30 (A17), U2.30 (A17), U3.30 (A17), U4.30 (A17)
A19: IC1.47 (A19), IC2.2 (I2), IC3.14 (IO1), IC5.10 (I10), IC6.4 (I4/PD), J3.37, U1.1 (A18), U2.1 (A18), U3.1 (A18), U4.1 (A18)
A20: IC1.48 (A20), IC2.3 (I3), J3.39, J6.2
A21: IC1.50 (A21), IC2.4 (I4/PD), J3.41, J6.3
A22: IC1.51 (A22), IC2.5 (I5), J3.43, J6.4
A23: IC1.52 (A23), IC2.6 (I6), J3.45, J6.5
AS: IC1.6 (AS), IC2.13 (I13), IC5.1 (I1/CLK), IC6.2 (I2), J3.47
BERR: IC1.22 (BERR), IC6.23 (IO10), J3.49, R10.1
BG: IC1.11 (BG), J3.51
BGACK: IC1.12 (BGACK), J3.53, R9.1
BOOT: IC2.9 (I9), IC5.21 (IO8)
BR: IC1.13 (BR), J3.55, R7.1
CLK: IC1.15 (CLK), IC6.1 (I1/CLK), J3.4, Q2.5 (OUT)
CPUSP: IC2.20 (IO7), IC5.22 (IO9), IC6.3 (I3)
CTSA: IC4.8 (IP0), IC8.6 (Y1), J1.6
CTSB: IC4.5 (IP1), IC10.4 (Y2), J2.6
D0: IC1.5 (D0), IC4.28 (D0), J3.61, U1.13 (D0), U3.13 (DQ0)
D1: IC1.4 (D1), IC4.18 (D1), J3.63, U1.14 (D1), U3.14 (DQ1)
D2: IC1.3 (D2), IC4.27 (D2), J3.64, U1.15 (D2), U3.15 (DQ2)
D3: IC1.2 (D3), IC4.19 (D3), J3.62, U1.17 (D3), U3.17 (DQ3)
D4: IC1.1 (D4), IC4.26 (D4), J3.60, U1.18 (D4), U3.18 (DQ4)
D5: IC1.64 (D5), IC4.20 (D5), J3.58, U1.19 (D5), U3.19 (DQ5)
D6: IC1.63 (D6), IC4.25 (D6), J3.56, U1.20 (D6), U3.20 (DQ6)
D7: IC1.62 (D7), IC4.21 (D7), J3.54, U1.21 (D7), U3.21 (DQ7)
D8: IC1.61 (D8), J3.52, U2.13 (D0), U4.13 (DQ0)
D9: IC1.60 (D9), J3.50, U2.14 (D1), U4.14 (DQ1)
D10: IC1.59 (D10), J3.48, U2.15 (D2), U4.15 (DQ2)
D11: IC1.58 (D11), J3.46, U2.17 (D3), U4.17 (DQ3)
D12: IC1.57 (D12), J3.44, U2.18 (D4), U4.18 (DQ4)
D13: IC1.56 (D13), J3.42, U2.19 (D5), U4.19 (DQ5)
D14: IC1.55 (D14), J3.40, U2.20 (D6), U4.20 (DQ6)
D15: IC1.54 (D15), J3.38, U2.21 (D7), U4.21 (DQ7)
DTACK: IC1.10 (DTACK), IC2.22 (IO9), IC4.10 (*DTALK), J3.57, R21.2
DUAIACK: IC4.41 (*IACK), IC5.23 (IO10)
DUAIRQ: IC4.24 (INTR), IC7.1 (I4), R16.2
DUASEL: IC3.20 (IO7), IC4.39 (CS)
E: IC1.20 (E), J3.10
EVENRAMSEL: IC2.14 (IO1), U4.22 (CE)
EVENROMSEL: IC2.16 (IO3), U2.22 (CE)
EXPSEL: IC2.19 (IO6), J3.18, J6.1
FC0: IC1.28 (FC0), IC3.21 (IO8), IC5.6 (I6), J3.20
FC1: IC1.27 (FC1), IC3.22 (IO9), IC5.5 (I5), J3.22
FC2: IC1.26 (FC2), IC3.23 (IO10), IC5.4 (I4/PD), J3.24
GND: C1.1, C2.1, C3.2, C4.2, C5.2, C6.2, C7.2, C8.2, C9.2, C10.2, C11.-, C12.2, C14.-, C15.-, C16.2, C17.-, C18.-, C19.-, C20.2, C21.-, C22.2, C23.2, C24.2, C25.2, C26.2, C27.2, C28.2, C29.2, C30.2, C31.2, C32.2, C33.2, C34.2, C35.2, C36.2, C37.2, C38.2, C39.2, C40.2, C41.1, C42.1, H1.1, H2.1, H3.1, H4.1, IC1.16 (GND@1), IC1.53 (GND@2), IC2.12 (GND), IC3.12 (GND), IC4.3 (IP3), IC4.22 (GND), IC4.42 (IP5), IC4.43 (IP4), IC5.12 (GND), IC6.12 (GND), IC6.13 (I13), IC7.5 (EI), IC7.8 (GND), IC7.10 (IO), IC8.2 (GND), IC9.2 (GND), IC10.2 (GND), IC11.2 (GND), IC12.1 (GND), IC12.5 (GND), IC12.10 (AGND), IC12.11 (GND), IC12.13 (TEST), IC12.15 (GND), IC12.25 (GND), IC12.35 (GND), IC12.47 (GND), IC12.51 (GND), IC13.2 (GND), IC13.5 (GND), IC15.1 (GND), J1.1, J2.1, J3.6, J4.6, J5.2, J9.2, J10.A1 (GND), J10.A12 (GND), J10.B1 (GND), J10.B12 (GND), J10.S1 (SHIELD), JP4.2 (B), Q2.4 (GND), R4.2, R5.1, R28.1, R30.1, U1.16 (GND), U2.16 (GND), U3.16 (VSS), U4.16 (VSS), U6.2 (GND), U8.2 (GND)
HALT: IC1.17 (HALT), IC5.15 (IO2), R31.1
HWRST: IC5.3 (I3), IC15.3 (Q)
IOSEL: IC2.18 (IO5), IC3.19 (IO6), J3.16
IPL0: IC1.25 (IPL0), IC7.9 (S0)
IPL1: IC1.24 (IPL1), IC7.7 (S1)
IPL2: IC1.23 (IPL2), IC7.6 (S2)
IRQ2: IC7.12 (I2), J3.28, R15.2
IRQ3: IC7.13 (I3), J3.14, R18.2
IRQ5: IC7.2 (I5), J3.26, R17.2
IRQ6: IC7.3 (I6), J3.30, R12.2
LDS: IC1.8 (LDS), IC2.8 (I8), IC3.18 (IO5), J3.32
LGEXP: IC2.10 (I10), JP4.1 (A), R8.2
unnamed: IC4.15 (OP3), LED2.K (C)
unnamed: IC4.16 (OP5), LED1.K (C)
unnamed: C1.2, IC4.36 (X1/CLK), Q1.1
unnamed: C2.2, IC4.37 (X2), Q1.2
unnamed: IC12.29 (ACBUS3), LED5.1 (K)
unnamed: IC12.30 (ACBUS4), LED6.1 (K)
unnamed: IC12.54 (BCBUS3), LED7.1 (K)
unnamed: IC12.55 (BCBUS4), LED8.1 (K)
unnamed: C41.2, IC12.2 (OSCI), Y2.1
unnamed: C42.2, IC12.3 (OSCO), Y2.2
unnamed: IC12.6 (REF), R30.2
unnamed: FB1.1, IC12.50 (VREGIN)
unnamed: IC12.14 (~RESET), R33.1
unnamed: IC13.3 (ON), SJ1.2
unnamed: IC13.4 (VIN), IC13.6 (VIN), J10.A4 (VBUS), J10.A9 (VBUS), J10.B4 (VBUS), J10.B9 (VBUS), SJ1.1, SJ2.1
unnamed: C13.2, IC15.5 (CV)
unnamed: C11.+, IC15.2 (TR), IC15.6 (THR), R27.1, S1.1 (S)
unnamed: J10.A5 (CC1), R5.2
unnamed: J10.B5 (CC2), R4.1
unnamed: LED1.A, R1.1
unnamed: LED2.A, R2.1
unnamed: LED3.A, R13.1
unnamed: LED4.A, R14.1
unnamed: LED5.2 (A), R6.1
unnamed: LED6.2 (A), R20.1
unnamed: LED7.2 (A), R22.1
unnamed: LED8.2 (A), R23.1
unnamed: Q2.1 (EN), R3.2
unnamed: R28.2, S1.3
unnamed: R26.1, R29.2, U8.1 (DO)
ODDRAMSEL: IC2.15 (IO2), U3.22 (CE)
ODDROMSEL: IC2.17 (I04), U1.22 (CE)
RESET: IC1.18 (RESET), IC4.38 (*RESET), IC5.16 (IO3), J3.36, LED4.K (C), R32.1
ROM_RW: JP3.2 (B), R11.2, U1.31 (PGM), U2.31 (PGM)
RTSA: IC4.32 (OP0), IC9.1 (IN_A), J1.2
RTSB: IC4.14 (OP1), IC11.3 (IN_B), J2.2
RUNLED: IC5.17 (I04), LED3.K (C)
RW: IC1.9 (R/W), IC2.11 (I11), IC4.9 (*R/*W), J3.59, JP3.1 (A), U3.29 (WE), U4.29 (WE)
RXDA: IC4.35 (RXDA), IC8.4 (Y2), J1.4
RXDB: IC4.11 (RXDB), IC10.6 (Y1), J2.4
SPICLK: IC4.30 (OP4), J4.2
SPICS: IC4.31 (OP2), J4.1
SPICS2: IC4.17 (OP7), J7.1
SPIMISO: IC4.40 (IP2), J4.4
SPIMOSI: IC4.29 (OP6), J4.3
TXDA: IC4.33 (TXDA), IC9.3 (IN_B), J1.5
TXDB: IC4.13 (TXDB), IC11.1 (IN_A), J2.5
UDS: IC1.7 (UDS), IC2.7 (I7), J3.34
USB_DN: IC12.7 (DM), J10.A7 (D-), J10.B7 (D-)
USB_DP: IC12.8 (DP), J10.A6 (D+), J10.B6 (D+)
VCC: C3.1, C4.1, C5.1, C6.1, C7.1, C8.1, C9.1, C10.1, C12.1, C13.1, C14.+, C15.+, C16.1, C17.+, C18.+, C19.+, C21.+, C22.1, C24.1, C25.1, C26.1, C27.1, C28.1, C29.1, C30.1, C31.1, C32.1, IC1.14 (VCC@1), IC1.49 (VCC@2), IC2.24 (VCC), IC3.24 (VCC), IC4.44 (VCC), IC5.24 (VCC), IC6.24 (VCC), IC7.4 (I7), IC7.11 (I1), IC7.16 (VCC), IC8.5 (VCC), IC10.5 (VCC), IC13.1 (VOUT), IC15.4 (R), IC15.8 (V+), J3.2, J4.5, J5.1, J9.1, JP1.2 (B), JP2.2 (B), Q2.8 (Vcc), R1.2, R2.2, R3.1, R7.2, R8.1, R9.2, R10.2, R11.1, R12.1, R13.2, R14.2, R15.1, R16.1, R17.1, R18.1, R19.1, R21.1, R27.2, R31.2, R32.2, SJ2.2, U1.32 (VCC), U2.32 (VCC), U3.32 (VCC), U4.32 (VCC), U6.1 (VIN), U6.3 (EN)
VCCUA: J1.3, JP1.1 (A)
VCCUB: J2.3, JP2.1 (A)
VMA: IC1.19 (VMA), J3.12
VPA: IC1.21 (VPA), J3.8, R19.2
WR: IC2.23 (IO10), U1.24 (OE), U2.24 (OE), U3.24 (OE), U4.24 (OE)

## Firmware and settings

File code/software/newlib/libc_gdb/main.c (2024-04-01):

#include <stdio.h>
#include <string.h>
#include <errno.h>
#include <rosco_m68k/debug.h>

#define BUF_SIZE    64

static void existing_file_test();
static void new_file_test();

static void afunc() {
    int a = 3 + 5;
    printf("Int is %d\n", a);
}

int main() {
    printf("Waiting for debugger attach...\n");    
    breakpoint();

    afunc();
}

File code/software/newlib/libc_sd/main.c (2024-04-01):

#include <stdio.h>
#include <string.h>
#include <errno.h>
#include <rosco_m68k/debug.h>

#define BUF_SIZE    64

static void existing_file_test();
static void new_file_test();

int main() {
    printf("## libc file test\n\n");

    existing_file_test();
    new_file_test();
    
    printf("Tests are done!\n");

    breakpoint();
}

static void do_read_test(char *fn) {
    FILE *f = fopen(fn, "r");

    if (f) {
        printf("File %s opened - reading\n", fn);
        char buffer[BUF_SIZE];
        int num;

        do {
            num = fread(buffer, 1, BUF_SIZE, f);

            if (num > 0) {
                printf("%.*s", num, buffer);
            } else if (num == -1) {
                printf("  Read failed: 0x%08x\n", errno);
            } else {
                if (feof(f)) {
                    printf("<--- EOF>\n");
                } else {
                    printf("<--- ERR>\n");
                }
            }
        } while (num > 0);
    } else {
        printf("Open failed: 0x%08x\n", errno);
    }

    fclose(f);
}

static void existing_file_test() {
    printf("### Read existing file\n");
    do_read_test("/sd/test.txt");
    printf("Existing file test done\n\n");
}

static void new_file_test() {
    printf("### Write / read new file\n");
    FILE *f = fopen("/sd/test2.txt", "w");

    if (f) {
        printf("File /sd/test2.txt opened - writing\n");
        char *buffer = "This is some data for a new file\nOf course, it is also rather awesome!\n\n";
        int total = 0;
        int num;

        do {
            num = fwrite(buffer, 1, strlen(buffer), f);

            if (num > 0) {
                total += num;
                printf("  Wrote %d bytes [%d of total %d done]\n", num, total, strlen(buffer));
            } else if (num == -1) {
                printf("  Write failed: 0x%08x\n", errno);
                break;
            }
        } while (total < strlen(buffer));
    } else {
        printf("Open failed: 0x%08x\n", errno);
    }

    fclose(f);

    do_read_test("/sd/test2.txt");

    printf("New file test done\n\n");
}

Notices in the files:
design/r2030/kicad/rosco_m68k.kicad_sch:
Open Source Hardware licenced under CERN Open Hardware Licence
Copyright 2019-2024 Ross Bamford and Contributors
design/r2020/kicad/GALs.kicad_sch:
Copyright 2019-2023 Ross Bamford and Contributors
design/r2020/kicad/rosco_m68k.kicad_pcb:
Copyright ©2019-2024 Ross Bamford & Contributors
